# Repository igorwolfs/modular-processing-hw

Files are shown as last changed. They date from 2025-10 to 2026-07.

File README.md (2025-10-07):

# MCU-BOARD

## Acoustic-carrier Project
The goal is to design a small CPU board, with some RAM and connectors, that can
- Drive the piezo-driver / inverter board
- Save about 1 second of data from 2 30 MHz ADC's
	- Reflection at origin-piezo
	- Transmission from origin to second-piezo
- Processing of the data on the MCU in the next few seconds
- Storage of the processed data on an SD-CARD
- Transmission of the processed data over Hi-Speed USB / Ethernet to a computer

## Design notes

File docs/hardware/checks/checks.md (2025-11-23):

# MCU
## STM32
- LPN: ok
- MPN: ok

### Schematic
- Pins OK -> Compared with output on footprint vs STM32 output
- Make still check BS0/BS1 for wrong outputs

### Footprint
- Check footprint dimensions
	- Looks good

## Resonator
- LPN: ok
- MPN: ok

### Schematic
- pin2, 4 -> GND
- pin 1, 3: connected to res
	- 4.7 pF capacitors

### Footprint
- Looks good

## Button
- LPN: ok
### Footprint
- ok

# SDRAM
## BA / BS
and bank address (BA), also
known as bank select (BS).

## Schematic
- Connections look ok

## Footprint
- Check pin number vs Symbol number
- Footprint: 
	- Package_SO:TSOP-II-54_22.2x10.16mm_P0.8mm
- SDRAM looks ok

# USB
## USB Receptacle
- USB_C_Receptacle_HRO_TYPE-C-31-M-12
- Looks good (footprints + pinout)

## USB ESD protection

- Package_TO_SOT_SMD:SOT-23-6

## Resistive pull-up
- Resistor_SMD:R_Array_Convex_4x0603
- Footprint: ok

## SDMMC
### Schematic
- pins vs footprint:

### Footprint

### Layout
TODO:
- Keep skew below 10 mm
- Add pull-up on cmd line?
	- CMD line must have pull-up as well
	- https://community.st.com/t5/stm32-mcus-products/using-sdmmc-sdio-and-fatfs-for-reading-sd-card-for-stm32l471vgt6/td-p/689667

DONE

## Connectors
- Plug_Hirose_DF40_2x40_DF40C-80DP-0.4V (DF40C-80DP-0.4V(51))
- Footprint: iw-connector:HRS_DF40C-80DP-0.4V(51)

### Footprint
- Looks correct -> number of pins is also correct
- Pin indicators (uneven / even), instead of counting as in jlc -> but ok

# ADC Frontend
- Reference buffering: checked, should work
## THS4521
- Looks ok
- Pins: ok
### Footprint: ok

## Everything else: looks ok

# Power
- AMS1117-3.3: looks ok

## Footprint package: looks OK

## SDRAM length matching

### First connection
- CLK: 38.7 mm
- A0..A12
	- A0: 46
	- A1: 46
	- A2: 47
	- A3: 47.9
	- A4: 40.3
	- A5: 36 mm
	- A6: 40.9 
	- A7: 39
	- A8: 35
	- A9: 34
	- A10: 44
	- A11: 34
	- A12: 35
- BS0..1: 
	- BS1: 34
	- BS0: 33
-> ALL OK
- D0..16
	- D0: 38.7
	- D1: 32
	- D2: 41
	- D3: 42
	- D4: 36.3
	- D5: 35
	- D6: 37
	- D7: 36.3
	- D8: 31
	- D9: 30
	- D10: 30
	- D11: 30.5
	- D12: 30.5
	- D13: 34
	- D14: 31.6
	- D15: 32.8
- Other
	- nRAS: 48
	- nCAS: 44
	- nWE: 47
	- LDQM: 47.5
	- UDQM: 37.2
	- nCKE0: 49

### Second connection
- CLK: 68 mm
- A0..A12
	- A0: 71.8
	- A1: 72
	- A2: 72
	- A3: 73
	- A4: 64
	- A5: 66
	- A6: 63
	- A7: 63
	- A8: 60
	- A9: 66
	- A10: 68
	- A11: 62
	- A12: 65
- BS0..1: 
	- BS1: 69
	- BS0: 66
- D0..16
	- D0: 64
	- D1: 62
	- D2: 69
	- D3: 66
	- D4: 62
	- D5: 61
	- D6: 61
	- D7: 60.3
	- D8: 60
	- D9: 60
	- D10: 62
	- D11: 65
	- D12: 63
	- D13: 66
	- D14: 61.3
	- D15: 61
- Other
	- nRAS: 74
	- nCAS: 68
	- nWE: 73
	- LDQM: 73
	- UDQM: 65
	- nCKE1: 65

## PSSI length matching
- PDCK: 34 mm
- D8: 56.3 mm
- D12: 54 mm
- D13: 51 mm
- D6, D7: 17 mm

Increase PDCK to 45 mmm
- Match everything to +-15 mm

## SDMMC length
- D0..D3
	- D0: 76
	- D1: 81
	- D2: 83
	- D3: 85
- CD: 88
- CMD: 81

# Differential Impedances
- ADC: OK
- USB: OK

# PSSI impedance

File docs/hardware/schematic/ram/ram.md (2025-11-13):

# CPU Memory Controller
## NOR Flash / PSRAM controller
- Asynchronous SRAM and ROM
- PSRAM (cellurar RAM)
- NOR Flash memory

## Clock speed
- Programmable continuous clock (FMC_CLK) output
	- Can be used as MCO for synchronous access (Read / Write)
- Maximum FMC clock is 150 MHz

# Types of RAM
## PSRAM
- Pseudo-static random access memory
	- Acts as DRAM, looks like SRAM
	- It has internal circuitry for memory refreshing

##  SRAM
Static random access memory. 
- Static: data retainment without refreshing

## DRAM
Dynamic random access memory
- Dynamic: needs refreshing
- Slower than SRAM

# Options

## PSRAM

It seems like PSRAM is a good option, apart from the fact that the biggest size in which I can find it is 64 MBit.

### IS66WVE4M16EBLL-70BLI
64 MBit PSRAM (8 MBytes)
- BGA package (TFBGA-48)
- 4.33 dollars

## SRAM
- Only one availabla seems one with QSPI, and SSOP package
- Seems like I can only find them in small sizes (at most 144 MBit), and at high sizes they are crazy expensive.

### VTI7064MSME
- Too slow (probably QSPI only)
- Good package
- Cheap
- 64 MBit (not enough)

### CY7C2665KV18
- 30 dollars
- 550 MHz clock support

### S27KL0642DPBHI020
- Self refreshing DRAM (PSRAM)
- BGA24
- Hyperbus
- 5.49 dollars

## SDRAM
- They seem to all be in TSOP package, none of them in BGA

### Winbond: W9825G6KH-6
Speed: up to 200 MBit/second

- TSOP-54-10.2mm (non BGA!!!)
- 166 MHz
- 256 Mbit (32 MByte)
- 1.38 dollars

#### Question 1
How can we access 256 MBit of data if there are only 13 address bits
- 2**13 = 8192 words.

### Micron: MT48LC16M16A2P-6A
- 4 Meg x 16 x 4: 256 MBit (32 MByte)
- 166 MHz
- 5.22 dollars
- TSSOP

### Micron MT48H16M32LFB-6
- MT48H16M32LFB5-6 IT:C TR
- 512 Mbit
- 4.95 dollars
- BGA package 
- Mobile LPSDR RAM

# Winbond: W9825G6KH-6
## Power
- Power supply: 3V3

## Symbol + footprint check
- PINS OK
- FOOTPRINT OK

# Examples
## Soldering Inkplate
Path: Soldered-Inkplate-MOTION-STM-board-hardware-design/CAD
### Decoupling Capacitance
- 2 x 1 uF
- 2 x 7 x 100 nF
- 2 x 10 nF
- 3 x 1 nF

### Ferrites
- None
- Vdd, vddq connected
## Icepi Zero

### Decoupling
- 7 x 22 nF
- 1 x 10 uF

### Ferrites
- None
- Vdd, vddq connected

# Implementation
## Trace lengths:
### Clock: 40 mm
### Address bus
- A0: 45 mm
- A1: 46.5 mm
- A2: 47 mm
- A3: 48 mm
- A4: 38 mm
- A5: 37 mm
- A6: 40 mm
- A7: 39 mm
- A8: 35 mm
- A9: 34 mm
- A10: 44 mm
- A11: 33.55 mm
- A12: 34.165 mm

### Data bus
- D0: 38.5 mm
- D1: 31.3 mm
- D2: 40 mm
- D3: 41 mm
- D4: 36.3 mm
- D5: 35.7 mm
- D6: 36.68 mm
- D7: 37.3 mm
- D8: 31 mm
- D9: 30 mm
- D10: 30 mm
- D11: 31 mm
- D12: 30 mm
- D13: 30 mm
- D14: 31.645 mm
- D15: 35 mm

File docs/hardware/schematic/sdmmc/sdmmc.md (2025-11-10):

# SDMMC

## Hardware design
### Pull-ups / downs
- CMD + DATA[0..3] lines must be pulled up by 10 kOhm resistors
	- https://docs.espressif.com/projects/esp-idf/en/stable/esp32/api-reference/peripherals/sd_pullup_requirements.html
	
## Pins

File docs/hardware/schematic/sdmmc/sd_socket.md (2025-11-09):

# The SD Socket
The SD card socket has 4 pads on the metal shielding and 11 pinouts (also pads, at the back). An online search reveals that the pinouts of these components are fairly standard. That’s understandable given the fungible / standardized nature of the cards themselves.

Many of the pins simply connect directly through to the pads of the SD card itself. So let’s consider those:

- DAT3 / CS
- CMD / DI
- VSS1
- VCC
- CLK / SCLK
- VSS2
- DAT0 / DO
- DAT1
- DAT2

The very small microSD cards have only 8 pins. On those there is only one VSS pin.

To these, the SD card slot adds three pins:

- Card Detect (CD)
- Common Switch
- Write Protect (WP)

Note: only eight of the pins are used in this project.

## Power Pins
Pins VSS1, VSS2 and VCC relate to power supply.

### Vss
VSS stands for voltage source and is where ground should be connected. On other schematics it may be labelled as GND.

### Vdd
VDD stands for voltage drain and is where positive power should be connected. On other schematics it may be labelled as VCC, which stands for voltage collector.

## Data Pins

SD cards can be operated in SPI (serial peripheral interface) mode or native operating mode. Because the SD card can be attached to most microcontrollers via a generic SPI interface or some GPIO ports it is a suitable for many projects. Therefore we will discuss pins as they are used in this mode.

### SPI 
The SPI protocol defines a host and slave relationship, described at http://elm-chan.org/docs/spi_e.html 105. This is important to remember in the reading of the pins below. Also, throughout these notes I use the terms host and microcontroller interchangeably.

### DAT3 / CS

This is the Data 3 pin in native mode and Chip Select pin in SPI mode. It is used by the SPI host (in our case, the microcontroller) to indicate that it’s communicating with the slave. It can also be used by the slave to indicate to the host it is ready to communicate.

This functionality means the data out and data in pins can be part of a shared data bus (with other SPI slave devices on it).

### CMD / DI
This is the Command pin in native mode and Data In pin in SPI mode. It is used by the SPI host to send serial data (bit by bit) to the SD card (the slave) and is sometimes referred to as Master-Out Slave-In (MOSI).

### DAT0 / DO
This is the Data 0 pin in native mode and Data Out pin in SPI mode. It is used by the SPI slave to send serial data (bit by bit) to its host (the microcontroller) and is sometimes referred to as Master-In Slave-Out (MISO).

### CLK / SCLK
This is the Clock pin in both modes. It is used by the SPI host to provide a clock pulse for the purposes of sending and receiving data on the DI and DO pins.

## Card Slot Pins
### Card Detect (CD)

This pin is used to detect whether a card has been inserted in the slot. The mechanism by which this is done seems common across slot models (based on a random sampling of datasheets available online): the pin is connected to a mechanical switch which closes when the card is inserted and connects to ground on the other side. On the one we are using, the switch mechanism is exposed and clearly visible on the top of the slot (in the cut-away section of the shielding). Insert a card and you will see how the bent piece of metal (part of the shielding) touches another piece of metal. You can use a multimeter to test that the second piece of metal is connected to the CD pin and the bent piece (and indeed the entire shielding) is connected to ground.

To use the card detect functionality you would connect the CD pin to a positive power rail via a pull-up resistor so that you get a high signal when the slot is empty and a low signal when a card is inserted. This functionality is not used in this project.

This pin is also connected to the Common pin when a card is inserted and disconnected from the Common pin when there is no card inserted. This is an alternative way of using the pin.

### Write Protect (WP)
This pin is used to detect whether an inserted card has got Write Protect enabled. As with the CD pin, this is connected to ground when a card is inserted Write Protect on and you would need to have it pulled-up in order to use it.

As with the CD pin, this pin is connected to the Common pin when Write Protect is inserted and otherwise disconnected from the Common pin.

### Common Switch
Both the CD and WP pins above are connected to this pin, in addition to ground, when they are activated, providing another way for us to implement that functionality.

# Source:
- https://community.circuitmess.com/t/understanding-the-sd-card-slot/2801

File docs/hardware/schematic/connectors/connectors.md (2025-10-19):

# Connectors

We have 2 options
- Using high-speed edge connectors
- Using high-speed vertical connectors
- Using high-speed 90-degree angle connectors

## 90 degree vertical connectors
The main issue with those kind-of connectors is the pricepoint. Mechanical connectors with the ability to hold other PCB's at a 90 degree up-right are pretty expensive.

## vertical connectors
They are cheaper, however in order to use those we need
- OR mechanically small components in the space between the 2 boards (otherwise they mide impede the connection between the 2 boards)
- OR double-sided component assembly

Given the lower price-point we're aiming for, we'd want to do single-sided assembly only. Connectors put on top won't make the board connect unless we put the larger components on one side and only connect on the edge of the board.

The advanced ones of this version also only work for standard assembly, not for economic assembly.

### HC-PBB40C-100DS-0.4V-4.0-02
- VERY EXPENSIVE: 1.5 euros a pop
- Economic assembly

###  HRS Hirose
- Price is OK (0.69 + 0.94) for 90 connections
- DF40C-90DS-0.4V(51)
- DF40C-90DP-0.4V(51)
- Enough in stock
- Economic assembly

- There's a 100 or even a 120 pin variant of it as well: might be a better option, in this case we need only a single one
	- 120 is the biggest one -> But not that many available. 
	- Take either the 100 or the 90 pin variant.
	- 90 pins -> max 45 connections (if no power)
	- 100 pins -> max 50 connections (if no power)

BIG PRO:
- It seems like the height of these connectors can be higher than other components
- So we might get away with putting it centrally on the boards with other components around it instead of banning it to the edge because it would otherwise interfere with other IC's mechanically

## Edge-board connectors
Edge-board connectors are a good alternative, since they need to only be placed "on the edge".
They are however pretty expensive and there's not that many of them available with good pin amounts.

### DF36-15S-0.4V(51)
- 0.446 euros per piece
- Economic assembly

# Choice
- DF40C-80DP-0.4V(51)

Stacking height: 1.5 mm

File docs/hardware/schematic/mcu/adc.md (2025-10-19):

# ADC (STM32H723ZGTx)
3 ADC's:
- 2 16 bits ADC's
	- ADC1, ADC2
	- Interleaved mode
	- Can work at 7.2 MHz
	- 16-bit ADC1 and ADC2 in double-interleaved mode at 7.2 MHz
	- 3/4 fast channels (PA6, PB1, PC4, PF11, PF13)
	- 11/12 slow channels
- ADC3 at 7.1 - 8.3 MSPS (12 bits)
	- 2 direct channels (PA0_C, PA1_C, PC2_C and PC3_C)
	- 6 fast channels

## Channel choice

3. Direct channels are connected to analog I/Os (PA0_C, PA1_C, PC2_C and PC3_C) to optimize ADC performance.
4. Fast channels correspond to PA6, PB1, PC4, PF11, PF13 for ADCx_INPx, and to PA7, PB0, PC5, PF12, PF14 for
ADCx_INNx.

Direct channels: connected to analog I/Os 
- PA0_C, PA1_C, PC2_C and PC3_C
	- So connect the 2 ADC's to one of these pins in interleaved mode
	- Choose PA0_C/PA1_C -> fast channel

Fast channels:
- PA6, PB1, PC4, PF11, PF13 for ADCx_INPx
- PA7, PB0, PC5, PF12, PF14 for ADCx_INNx
	- Connect the 3rd channel to one of the INPx pins
	- Choose PB0/1 -> fast channel

## Min / Max values

## Modelling
- Sample-and-hold capacitor: 4 pF
- Sampling time: 1.5-810.5 	times  1/f_adc
- Equivalent static impedance
	- Varies between 170 ohms and 26.5 kOhm
	- Table 78. Minimum sampling time vs RAIN (16-bit ADC)(1)(2) gives a more detailed image of the ADC input impedance

### Internal buffering
- The ADC requires an external on-chip buffer?
	- It does, the impedance of the signal will likely be too high, even coming from a buffering board.
	- So we'll go for an on-CPU differential-input ADC sampling

# ADC Model
## Connection diagram (Figure 38)
- $R_{ADC}$
- $C_{ADC}$
- $C_{parasitic}$: PCB capacitance + pad capacitance (4 pF)
- $R_{source}$

## Parasitics
### 12-bit ADC
-

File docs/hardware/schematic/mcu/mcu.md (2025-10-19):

# Possible Choices

## STM32H72

- PRO: 
	- better ecosystem
	- Non-BGA
	- Easier development
	- DSP capabiltiy
	- SRAM/SDRAM/PSRAM (max frequency: 150 MHz)
- CON: 
	- more expensive
	- No RGMII
	- External RAM required

## Allwinner

- PRO:
	- Non-BGA
	- Cheaper
	- RGMII
- CON:
	- parallel inputs channel?
	- Support?

It seems in general that Allwinner is not used that often in devices.

# CPU requirements
The most important requirements for the CPU are
- There must be an ethernet interface (preferably RGMII, RMII also allowed)
- There must be a ULPI interface for HI-SPEED USB2.0
- There must be an SDRAM / SRAM / PSRAM  controller
- The clock speed must be above 200 MHz, the data to be read from the ADC (MS)
	- This one has a 10-bit pin interface.
- The package MUST NOT be a BGA, these are way too hard to debug.
- 1 MCO output to drive the ADC

## ADC
### Internal ADC
- Single / dual channel ADC
- 

### Alternative
- Downsampling / decimation of ADC data before in small DSP CPU

## USB
- ULPI interface

## SDRAM
### Data transfer requirements
- Data transfer:
	- 30 MHz x 2 bytes -> 57.3 Mbytes / second
	- Should be able to save at least a second of data

### Peripheral (stm32h72)
FMC (Flexible memory controller), can handle
- SRAM
- NOR flash / OneNAND flash
- PSRAM
- NAND
- DRAM (SDRAM Mobile LPSDR SDRAM)

#### Busses
- Address bus
	- Single address bus for all peripherals
- Different chip select for all peripherals
- Data bus
	- 8, 16 or 32-bits wide

#### Specs (SDRAM)
- SDRAM: Maximum speed for synchronous access is:
	- The FMC_CLK / FMC_SDCLK frequency divided by 2
- Address bit 13 max
- 2 NSS bits
- Write / Read fifos (16x32 bits)

Check the devboard for comparison
- SDRAM conflicts with

#### Banks
Bank 1 (NOR / PSRAM)
- Chip Selects: can handle 4x64 MB = 256 MB

Bank 2, 4
- Not used

Bank 3:
- Addressing NAND flash memory devices

Bank 5, 6:
- SDRAM devices: each bank here can handle 4 x 64 = 256 MB -> 512 MB togethery
- NOTE: SDRAM and ULPI interface are mutually exclusive!

## Ethernet
- RGMII interface

## DSP
- Full DSP instruction set

### FMAC
- Fixed point multiplier and accumulator
	- 16x16 bit multiplication
	- Can realize FIR and IIR filters

## SPI
### Specs
- SPI, QSPI, OCTSPI all possible 
	- OCTSPI mostly used for hyperbus (memory)
- Max SPI speed

## Clock output
- 2 x MCO output

Note: Input clock for MS9280 is +5 / +3V3 CMOS

## Parallel interfaces
Note: 
- The input data comes from the MS9280 A/D converter at 35 MHz. CMOS 3V3 or CMOS 5V (depending on input voltage)
	- LOW: 0.4 V
	- High: 2.8 V

### Camera interface
- 8-14 bit camera interface
- DCMII: CMOS 8-14 bit parallel interface, with data-rates up to 140 Mbyte/s at a 80 MHz clock

### 16-bit parallel slave synchronous interface
- CMOS / Parallel LVDS style serializer
	- PSSI: synchronou 8/16-bit data in/out slave
		- contains 8-word fifo
		- Can reach up to 140 MByte/s, 80 MHz pixel clock
		- So time multiplexing is A POSSIBILITY!
Choose this one.

### GPIO sampling + DMA
- timer with automatic input sampling and passing on to DMA

## DMA
### DMA2D
- 

# CPU Peripheral Selection
## FMC
FMC 2xSDRAM bus since SDRAM is faster and cheaper. It's the only one providing adequate speed.

### Signals
- Address bus (13 bits): A0..A12
- SDNWE (WE)
- CKE1, CKE2: 2 separate clock enable signals, one for each SDRAM
- NE1, NE2: (NOT) chip enable, one for each SDRAM
- BL0, BL1: Upper and lower byte enable for IC.
- NCAS: CAS# (column select for address)
- NRAS: RAS# (row select for address)

## Parallel Bus
### PSSI 
WARNING: mutually exclusive with the DCMI.

Parallel synchronous slave
- 8 / 16-bit communication between MCU's / MCU and FPGA.
	- Choose 16-bit communication

- Has DMA with 8-word FIFO.
- Data transfer polarity
	- CKPOL = 0:
		- Input sampled on CLOCK FALLING EDGE
		- Output driven on CLOCK RISING EDGE
	- CKPOL = 1:
		- Input sampled on CLOCK RISING EDGE
		- Output driven on CLOCK FALLING EDGE
	- Note: Setting PSSI into sending OR receiving mode can only be done when peripheral is deactivated

### Interrupt
- PSSI_OVR

### Speed
- AHB clock must be >=  2.5 times the frequency
- CLK MAX: 550 MHz
	- 550 / 2.5 = 220 MHz is the absolute maximum

### Pinout
- PSSI_RDY: (output) signal coming from the CPU itself indicating cpu readiness to sample data
- PSSI_VALID: (input) signal coming from another CPU / FPGA indicating data is valid
- PSSI_CLOCK:
	- Clock polarity (data can be captured / transmitted on EITHER rising OR falling edge)
- PSSI_DE: indicates data in the next cycle will be valid and will thus need to be sampled.

## USB
- Battery charger detection
- 12 Mbi/s (full-speed USB)

### Pinout
- USB_OTG_HS_DP
	- Internal 1k5 ohm on D+ line
- USB_OTG_HS_DM
- (USB_OTG_HS_ID) - UNNECESSARY, ONLY FOR USB micro A/B OTG
	- Determines whether device acts as host or peripheral
	- Only possible with USB micro A, micro B
- USB_OTG_HS_VBUS
	- VBUS (5 V) can be connected here
	- CPU has internal regulator capable of regulating its own 3v3 supply
	- Should be connected with a resistive divider of 5_INPUT - 4.7k - VBUS - 10k - GND
- (USB_OTG_HS_SOF) - UNNECESSARY, MOSTLY FOR AUDIO APPLICATIONS

### Question: Does the USB_OTG_HS_VBUS have any use as a Vsense pin when power is supplied externally?
- 

## SPI / SD-CARD
- Add an SPI peripiheral so I can read / write from an sd-card.
	- Might come in handy when saving large amounts of data is necessary (e.g.: when doing testing)

### Pinout
- SDMMC2_D0, SDMMC2_D1, SDMMC2_D2, SDMMC2_D3 (Data lines)
- SDMMC_CKN
- SDMMC2_CMD
- SDMMC2_CK

# Power Pin routing / Decoupling
- Check Table 2 in AN5419

## VDD
- 100 nF for each VDD
- 4.7 uF connected to one VDD

## VDDA
- 1 uF ceramic
- 100 nF close to the pin

## VBAT
- Connect to VDD
- 1 uF ceramic
- 100 nF close

## VCAP
- 100 nF close to each VCAP pin
- VCAP pins connected together

## VDD33USB
- 1 uF ceramic
- 100 nF ceramic (if USB reg not used)
- Internally tied to VDD

## VREF+
- 1 uF ceramic
- 100 nF ceramic
- Should be tied to the external reference voltage used for ADC
	- Check voltage used in ADC-board, perhaps provide this voltage to VREF if needed

## PDR_ON
- if HIGH: POR and PDR circuitry is ON
- if LOW: POR and PDR circuitry is OFF
	- So tigh high with 0 ohm resistor

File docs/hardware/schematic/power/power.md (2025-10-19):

# Power
We need a way to select one of 3 power input source
- 3V3 through connector
- 5 V through USB VBUS
- 5 V through pins

## Power consumption
- MCU: < 200 mA
- SDRAM: 60 mA x 2 = 120 mA
- ADC frontend: 5 mA

So: 330 mA * 1.3 V = 430 mWatt max dissipation.

Use the AMS1117-3.3

## Solution
- Buck converter
- LDO
	- The power required here is not that high. 
	- An LDO should do the job if isolated enough.
	- Warning: 
		- The dropout voltage might be too high. So you must make sure that you have an ideal diode in parallel driving the load in case the input voltage is 3V3
			- Or maybe foresee 2 pins here

So TODO:
- 1 connection from vbus to LDO
- 1 connection from piezodriver-vin-connector to LDO (in case supply 5 V)

So 2x2 connector here:

- 1 connection from LDO to 3V3
- 1 connection from large vin-connector to 3V3 (in case)
- 1 connection from piezodriver-vin-connector to 3V3

So 3x2 connector here:

## Overvoltage protection
- Add a resettable overcurrent fuse
- Add reverse voltage breakdown protection
	- Choose SMF3.3CA for the input at 3V3
	- Choose SMF7.0CA for the input at 5V-6V

Diode package: SOD-123FL

### Package check
- Dimensions look good

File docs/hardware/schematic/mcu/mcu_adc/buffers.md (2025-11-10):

# Buffer requirements
- GBW of at least 10 MHz

# Buffer examples
## INA333 (instrumentatino)
- BW: 150 kHz
- SR: 0.16 V/us
- Noise
	- @1kHz: 50 nV/sqrt(Hz)
- https://www.ti.com/lit/ds/symlink/ina333.pdf?ts=1760662953933

## OPA695 (precision)
- Good bandwidth
- More expensive

## AD8031
- GBW: 80 MHz
- SR: 30 V/us
- Price: 2+ euros
- Noise
	- @1kHz: 15 nV/sqrt(Hz)
- https://jlcpcb.com/api/file/downloadByFileSystemAccessId/8588901762816622592

## LTC6268
- Good bandwidth (500 MHz)
- Very low input impedance ()
- WAAAYY too expensive

## THS4521
- price: 0.8 $
- GBW: 145 MHz
- SR: 490 V/us
- Input voltage noise
	- > @10kHz
		- 4.6 nV/sqrt(Hz)
- Noise
	- @100 kHz: 
- Good option, bandwidth 40.7 MHz
- Maybe even a bit too much for our application

Seems like the best option
- The only thing that is quite shitty is the DC-offset for this one.

# THS4521
Images adc12, and adc3 were the resulting choices, some simulations can be found in the simulations/tina_ti folder that show the transfer function of these buffers with a dynamic load modelled after the stm32 parameters found in the datasheet.

# Vref requirement
- What should the vref be?
	- buffered vdda/2?
	- vdda?

## Measurement range for the dfferential ADC
### Table 184. ADC characteristics(1)(2) (continued)
- Conversion voltage range: 
	- 0..VREF+
- Common mode input voltage:
	- -Vref/2-10% .. Vref/2+10%

### What is the point of vref+?

It can be
####  Internal
#### External
- Then it should be supplied

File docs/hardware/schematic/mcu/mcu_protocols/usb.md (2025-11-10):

# USB
- a USB-pull-up resistor should be internal
	- Check reference schematic for nucleo
	- Check application ntoe

# SWD
- SWD-bus has no pull-ups present on the nucleo board.
- SWD-bus has both pull-ups and pull-downs present.
	- NJTRST: internal PU
	- SWDIO: pu
	- SWCLK: pd

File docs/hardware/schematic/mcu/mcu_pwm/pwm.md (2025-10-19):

# MCU PWM
- Advanced control timers: TIM1, TIM8
- We must generate 4 complementary signals at frequencies up to 10 MHz.

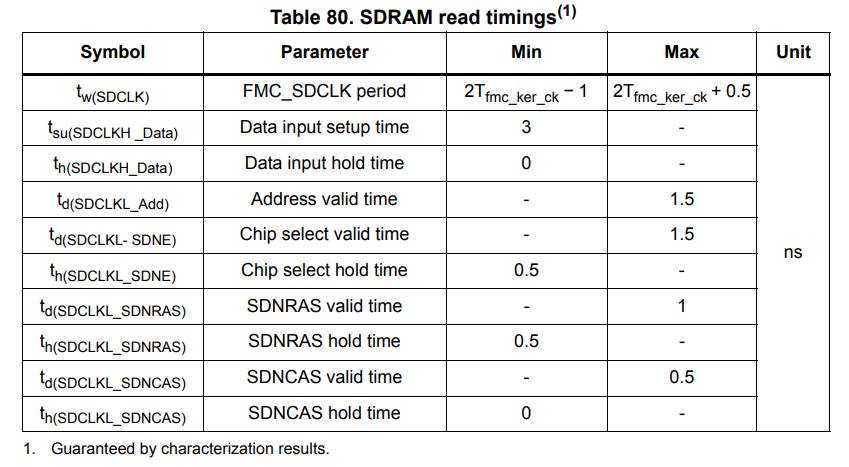
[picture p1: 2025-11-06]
docs/hardware/layout/FMC/rtime_st.png

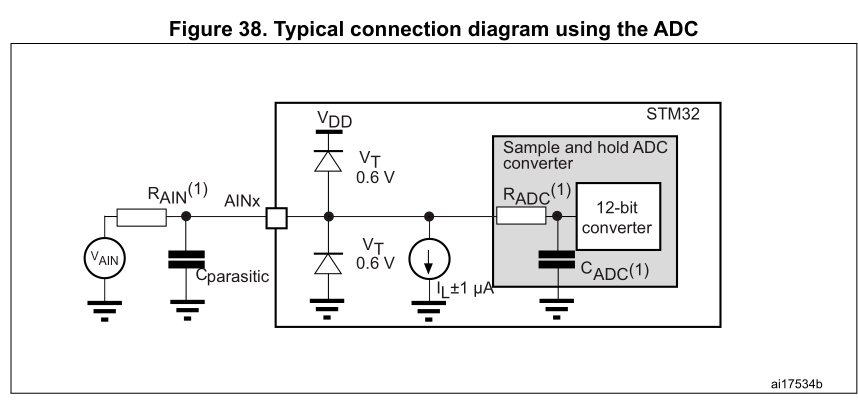
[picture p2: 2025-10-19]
docs/hardware/schematic/mcu/images/adc_connection_diagram.png

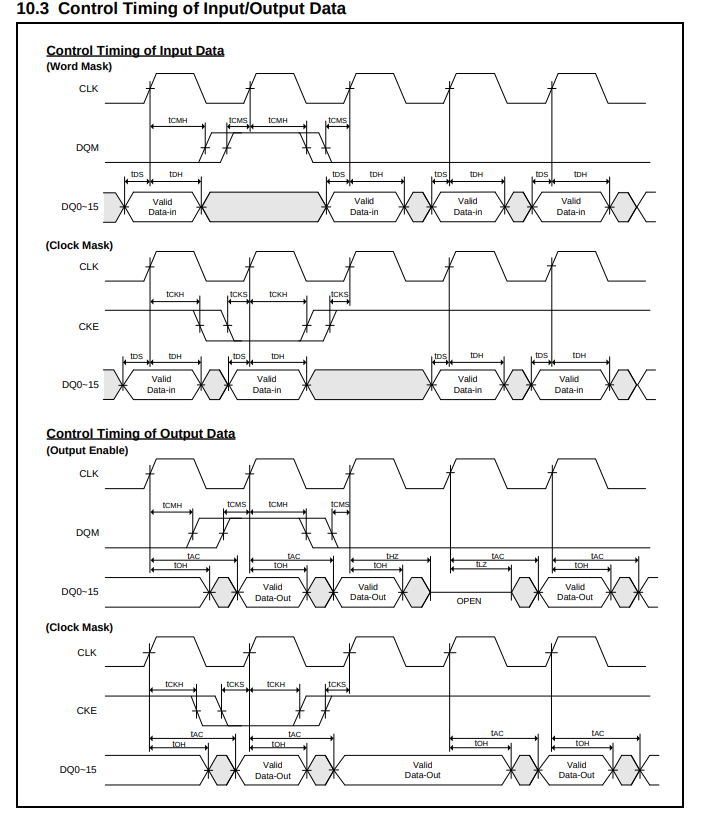
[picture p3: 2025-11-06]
docs/hardware/layout/FMC/rwwave_wb.png

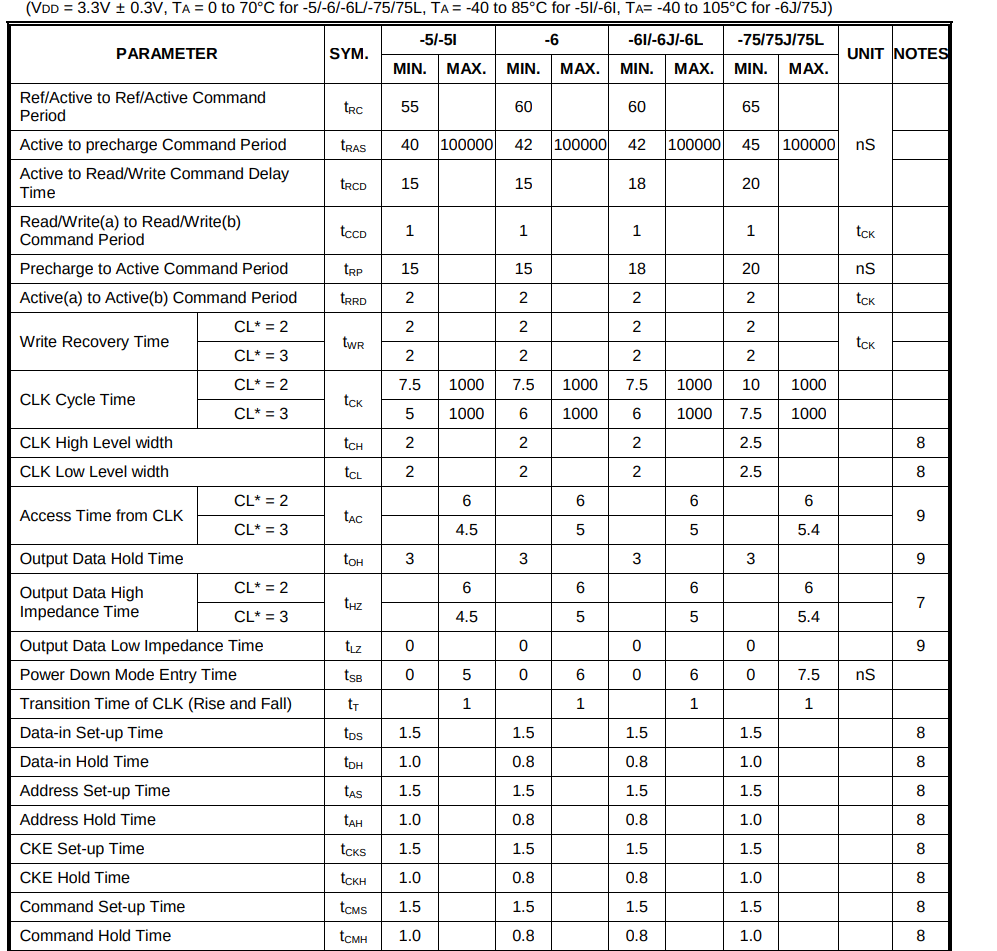
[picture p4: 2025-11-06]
docs/hardware/layout/FMC/rwtime_wb.png

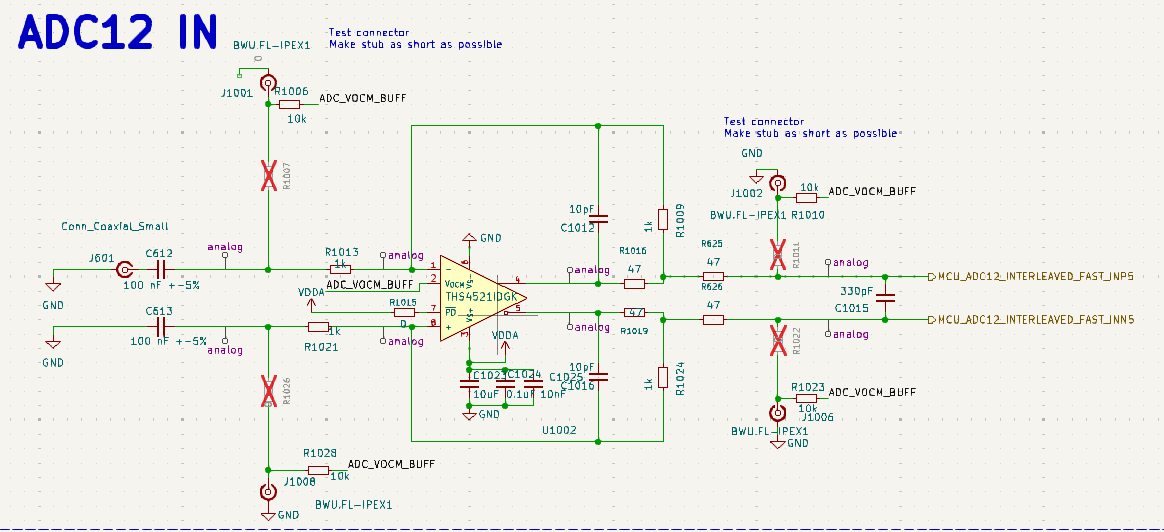
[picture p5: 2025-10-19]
docs/hardware/schematic/mcu/mcu_adc/images/adc12.png

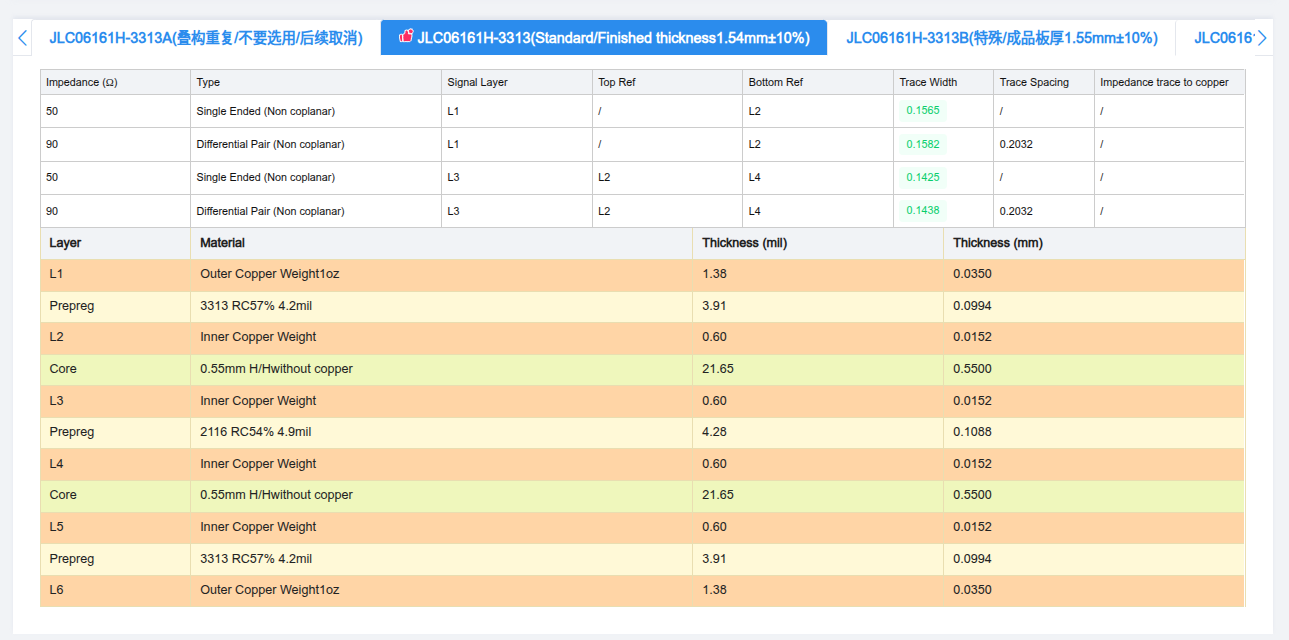
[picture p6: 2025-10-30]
docs/hardware/layout/impedance/jlc06161h-3313.png

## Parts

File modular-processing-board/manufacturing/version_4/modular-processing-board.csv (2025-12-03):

Reference | Qty | Value | Footprint | LPN | MPN
C201,C1227 | 2 | 20pF | Capacitor_SMD:C_0402_1005Metric | C1554 | 0402CG200J500NT
C202,C203,C204,C205,C206,C207,C208,C209,C210,C211,C212,C213,C214,C216,C217,C218,C220,C222,C224,C301,C302,C303,C304,C305,C306,C307,C308,C309,C310,C311,C313,C401,C601,C604,C605,C606,C607,C608,C617,C807,C1024,C1101,C1103 | 43 | 0.1uF | Capacitor_SMD:C_0402_1005Metric | C307331 | CL05B104KB54PNC
C215,C219,C221,C223 | 4 | 1uF | Capacitor_SMD:C_0805_2012Metric | C28323 | CL21B105KBFNNNE
C312,C701,C702,C703,C1107 | 5 | 22uF | Capacitor_SMD:C_0603_1608Metric | C59461 | CL10A226MQ8NRNC
C602,C618,C1025 | 3 | 10nF | Capacitor_SMD:C_0402_1005Metric | C15195 | CL05B103KB5NNNC
C603 | 1 | 220nF | Capacitor_SMD:C_0402_1005Metric | C16772 | CL05B224KO5NNNC
C609,C615,C1012,C1016 | 4 | 10pF | Capacitor_SMD:C_0603_1608Metric_Pad1.08x0.95mm_HandSolder | C1634 | CL10C100JB8NNNC
C610,C612,C613,C614 | 4 | 100nF | Capacitor_SMD:C_0603_1608Metric | C14663 | CC0603KRX7R9BB104
C611,C1015 | 2 | 330pF | Capacitor_SMD:C_0603_1608Metric_Pad1.08x0.95mm_HandSolder | C1664 | CL10C331JB8NNNC
C616,C619,C813 | 3 | 4.7uF | Capacitor_SMD:C_0402_1005Metric | C23733 | CL05A475MP5NRNC
C804,C805 | 2 | 220pF | Capacitor_SMD:C_0402_1005Metric | C1530 | 0402B221K500NT
D201,D401,D602 | 3 | RED | LED_SMD:LED_0603_1608Metric | C2286 | KT-0603R
D703 | 1 | SMF3.3CA | Diode_SMD:D_SOD-123F | C19077496 | SMF3.3CA
F2 | 1 | BSMD1812-050-15V | Fuse:Fuse_1812_4532Metric | C883139 | BSMD1812-050-15V
FID101,FID102,FID103,FID104 | 4 | Fiducial | Fiducial:Fiducial_1mm_Mask2mm
H101,H102,H103 | 3 | MountingHole | MountingHole:ToolingHole_1.152mm
J201 | 1 | Conn_ARM_SWD_TagConnect_TC2030 | Connector:Tag-Connect_TC2030-IDC-FP_2x03_P1.27mm_Vertical
J202 | 1 | Conn_02x06_Odd_Even | Connector_PinHeader_2.54mm:PinHeader_2x06_P2.54mm_Vertical
J401 | 1 | TF01A | iw-memory:TF01A | C2889258 | TF-01A
J501 | 1 | Plug_Hirose_DF40_2x40_DF40C-80DP-0.4V | iw-connector:HRS_DF40C-80DP-0.4V(51) | C294544 | DF40C-80DP-0.4V(51)
J502 | 1 | Conn_02x06_Odd_Even | Connector_PinSocket_2.54mm:PinSocket_2x06_P2.54mm_Vertical
J601,J604 | 2 | Conn_Coaxial_Small | Connector_Coaxial:SMA_Amphenol_901-144_Vertical | C496549 | BWSMA-KE-Z001
J602,J1001 | 2 | BWU.FL-IPEX1 | iw-connector:BWU.FL-IPEX1 | C5137195 | BWU.FL-IPEX1
J701 | 1 | Conn_02x02_Odd_Even | Connector_PinHeader_2.54mm:PinHeader_2x02_P2.54mm_Vertical
J801 | 1 | TYPE-C-31-M-12 | Connector_USB:USB_C_Receptacle_HRO_TYPE-C-31-M-12 | C165948 | TYPE-C-31-M-12
JP202 | 1 | SolderJumper_2_Bridged | Jumper:SolderJumper-2_P1.3mm_Bridged2Bar_Pad1.0x1.5mm
JP602 | 1 | SolderJumper_2_Open | Jumper:SolderJumper-2_P1.3mm_Open_Pad1.0x1.5mm
L701 | 1 | GZ2012D101TF | Inductor_SMD:L_0805_2012Metric | C1015 | GZ2012D101TF
R201 | 1 | 4.7k | Resistor_SMD:R_0402_1005Metric | C25900 | 0402WGF4701TCE
R203,R207,R217,R218,R616,R620,R1001,R1015,R1201 | 9 | 0 | Resistor_SMD:R_0603_1608Metric | C21189 | 0603WAF0000T5E
R206,R209 | 2 | 1k | Resistor_SMD:R_0402_1005Metric | C11702 | 0402WGF1001TCE
R208,R401,R402,R608,R609,R610,R612,R627,R628,R629,R1006 | 11 | 10k | Resistor_SMD:R_0603_1608Metric | C25804 | 0603WAF1002T5E
R210,R216 | 2 | 470 | Resistor_SMD:R_0402_1005Metric | C25117 | 0402WGF4700TCE
R214,R215,R614,R615,R617,R618,R625,R626,R1016,R1019 | 10 | 47 | Resistor_SMD:R_0603_1608Metric | C23182 | 0603WAF470JT5E
R601,R603,R605,R606,R611,R613,R619,R621,R1009,R1013,R1021,R1024 | 12 | 1k | Resistor_SMD:R_0603_1608Metric | C21190 | 0603WAF1001T5E,0603WAF1001T5E
R602 | 1 | 75 | Resistor_SMD:R_0603_1608Metric | C4275 | 0603WAF750JT5E
R604 | 1 | 1k5 | Resistor_SMD:R_0603_1608Metric | C22843 | 0603WAF1501T5E
R607 | 1 | 4.7k | Resistor_SMD:R_0603_1608Metric | C23162 | 0603WAF4701T5E
R703 | 1 | 1k5 | Resistor_SMD:R_0402_1005Metric | C25867 | 0402WGF1501TCE
R804,R805 | 2 | 5.1k | Resistor_SMD:R_0603_1608Metric | C23186 | 0603WAF5101T5E
R809,R810 | 2 | 33k | Resistor_SMD:R_0603_1608Metric | C4216 | 0603WAF3302T5E
RN707 | 1 | 4x10k | Resistor_SMD:R_Array_Convex_4x0603 | C29718 | 4D03WGJ0103T5E
SW201,SW602 | 2 | SW_Push | iw-misc:SW_TS-1088-AR02016 | C720477 | TS-1088-AR02016
TP201,TP202,TP401,TP402,TP403,TP404,TP601,TP602,TP701 | 9 | TestPoint | Connector_PinSocket_1.27mm:PinSocket_1x01_P1.27mm_Vertical
U201 | 1 | STM32H723ZGTx | Package_QFP:LQFP-144_20x20mm_P0.5mm | C730146 | STM32H723ZGT6
U202,U401 | 2 | SRV05-4 | Package_TO_SOT_SMD:SOT-23-6 | C20615829 | SRV05-4A
U301,U302 | 2 | W9825G6KH-6 | Package_SO:TSOP-II-54_22.2x10.16mm_P0.8mm | C62246 | W9825G6KH-6
U601 | 1 | LMV321 | Package_TO_SOT_SMD:SOT-23-5 | C7972 | LMV321IDBVR
U602 | 1 | TL432DBZ | Package_TO_SOT_SMD:SOT-23 | C5184435 | TL432
U603,U1002 | 2 | THS4521IDGK | Package_SO:VSSOP-8_3x3mm_P0.65mm | C170157 | THS4521IDGKR
U701 | 1 | AMS1117-3.3 | Package_TO_SOT_SMD:SOT-223-3_TabPin2 | C6186 | AMS1117-3.3
Y201 | 1 | 8MHz | Crystal:Crystal_SMD_5032-2Pin_5.0x3.2mm | C115962 | X50328MSB2GI

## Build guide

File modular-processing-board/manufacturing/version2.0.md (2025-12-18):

# Schematic fixes
- Make sure the boot0 pin is pulled down, and there's a button to pull it high instead of having to manually connect a wire.

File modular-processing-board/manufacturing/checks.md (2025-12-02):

 # Checks
 - Are traces not wobbly?
	- Often times when traces are drawn around vias they end up being smeared out
- Are all connected zones merged? 
	- Kicad doesn't automatically 2 identical zones that are side by side together unless they actually overlap. To be on the safe side, make sure to merge all the zones

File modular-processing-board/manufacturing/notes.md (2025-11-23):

- Exporting Gerbers + Drill-files from kicad9: https://jlcpcb.com/help/article/how-to-generate-gerber-and-drill-files-in-kicad-9
- BOM + centroid generation: https://jlcpcb.com/help/article/How-to-generate-the-BOM-and-Centroid-file-from-KiCAD

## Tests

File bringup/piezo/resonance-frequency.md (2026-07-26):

# Questions
## How does one determine the resonance frequency?

Likely one can simply wire a coax with 2 wires to the piezo, and then connect it to a regulator multimeter, this would allow
- Series static capacitance measurement

Having it connected to a VNA can after a sweep give you
- The resonance frequency (frequency where the reactance is 0, and everything is purely converted into mechanical waves).

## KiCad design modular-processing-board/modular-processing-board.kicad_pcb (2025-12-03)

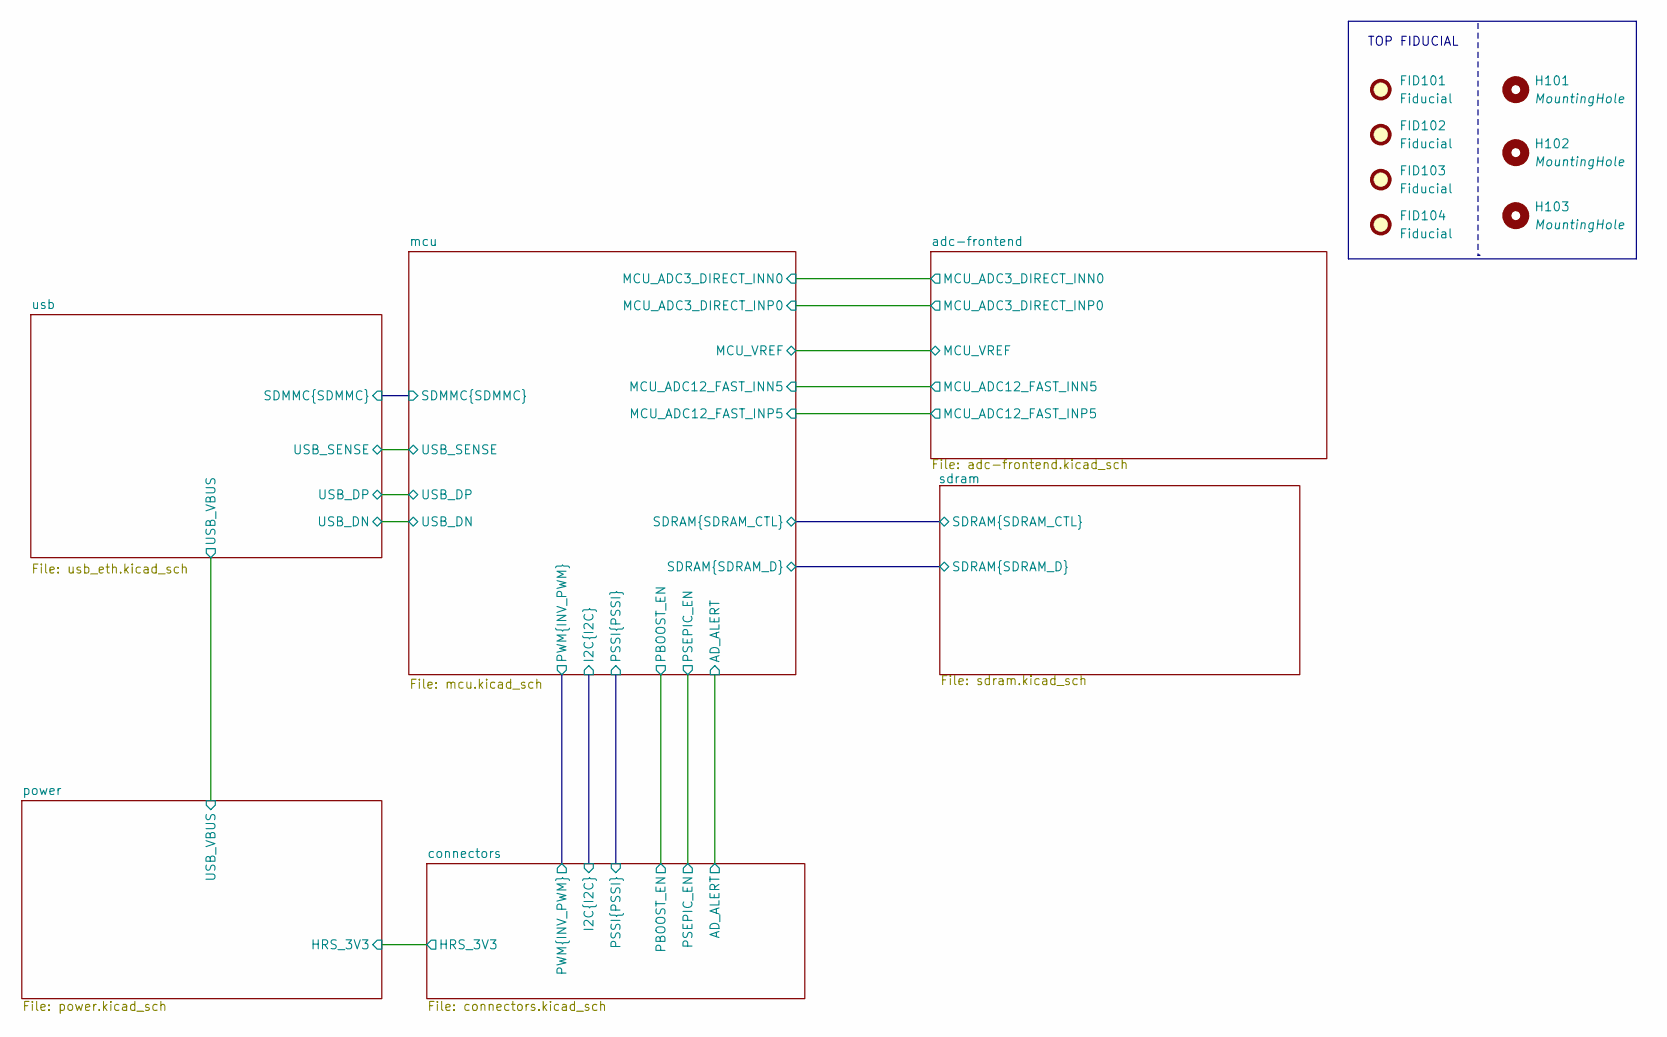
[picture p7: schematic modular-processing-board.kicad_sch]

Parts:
FID101, FID102, FID103, FID104: Fiducial; Fiducial_1mm_Mask2mm
H101, H102, H103: MountingHole; ToolingHole_1.152mm

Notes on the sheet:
TOP FIDUCIAL

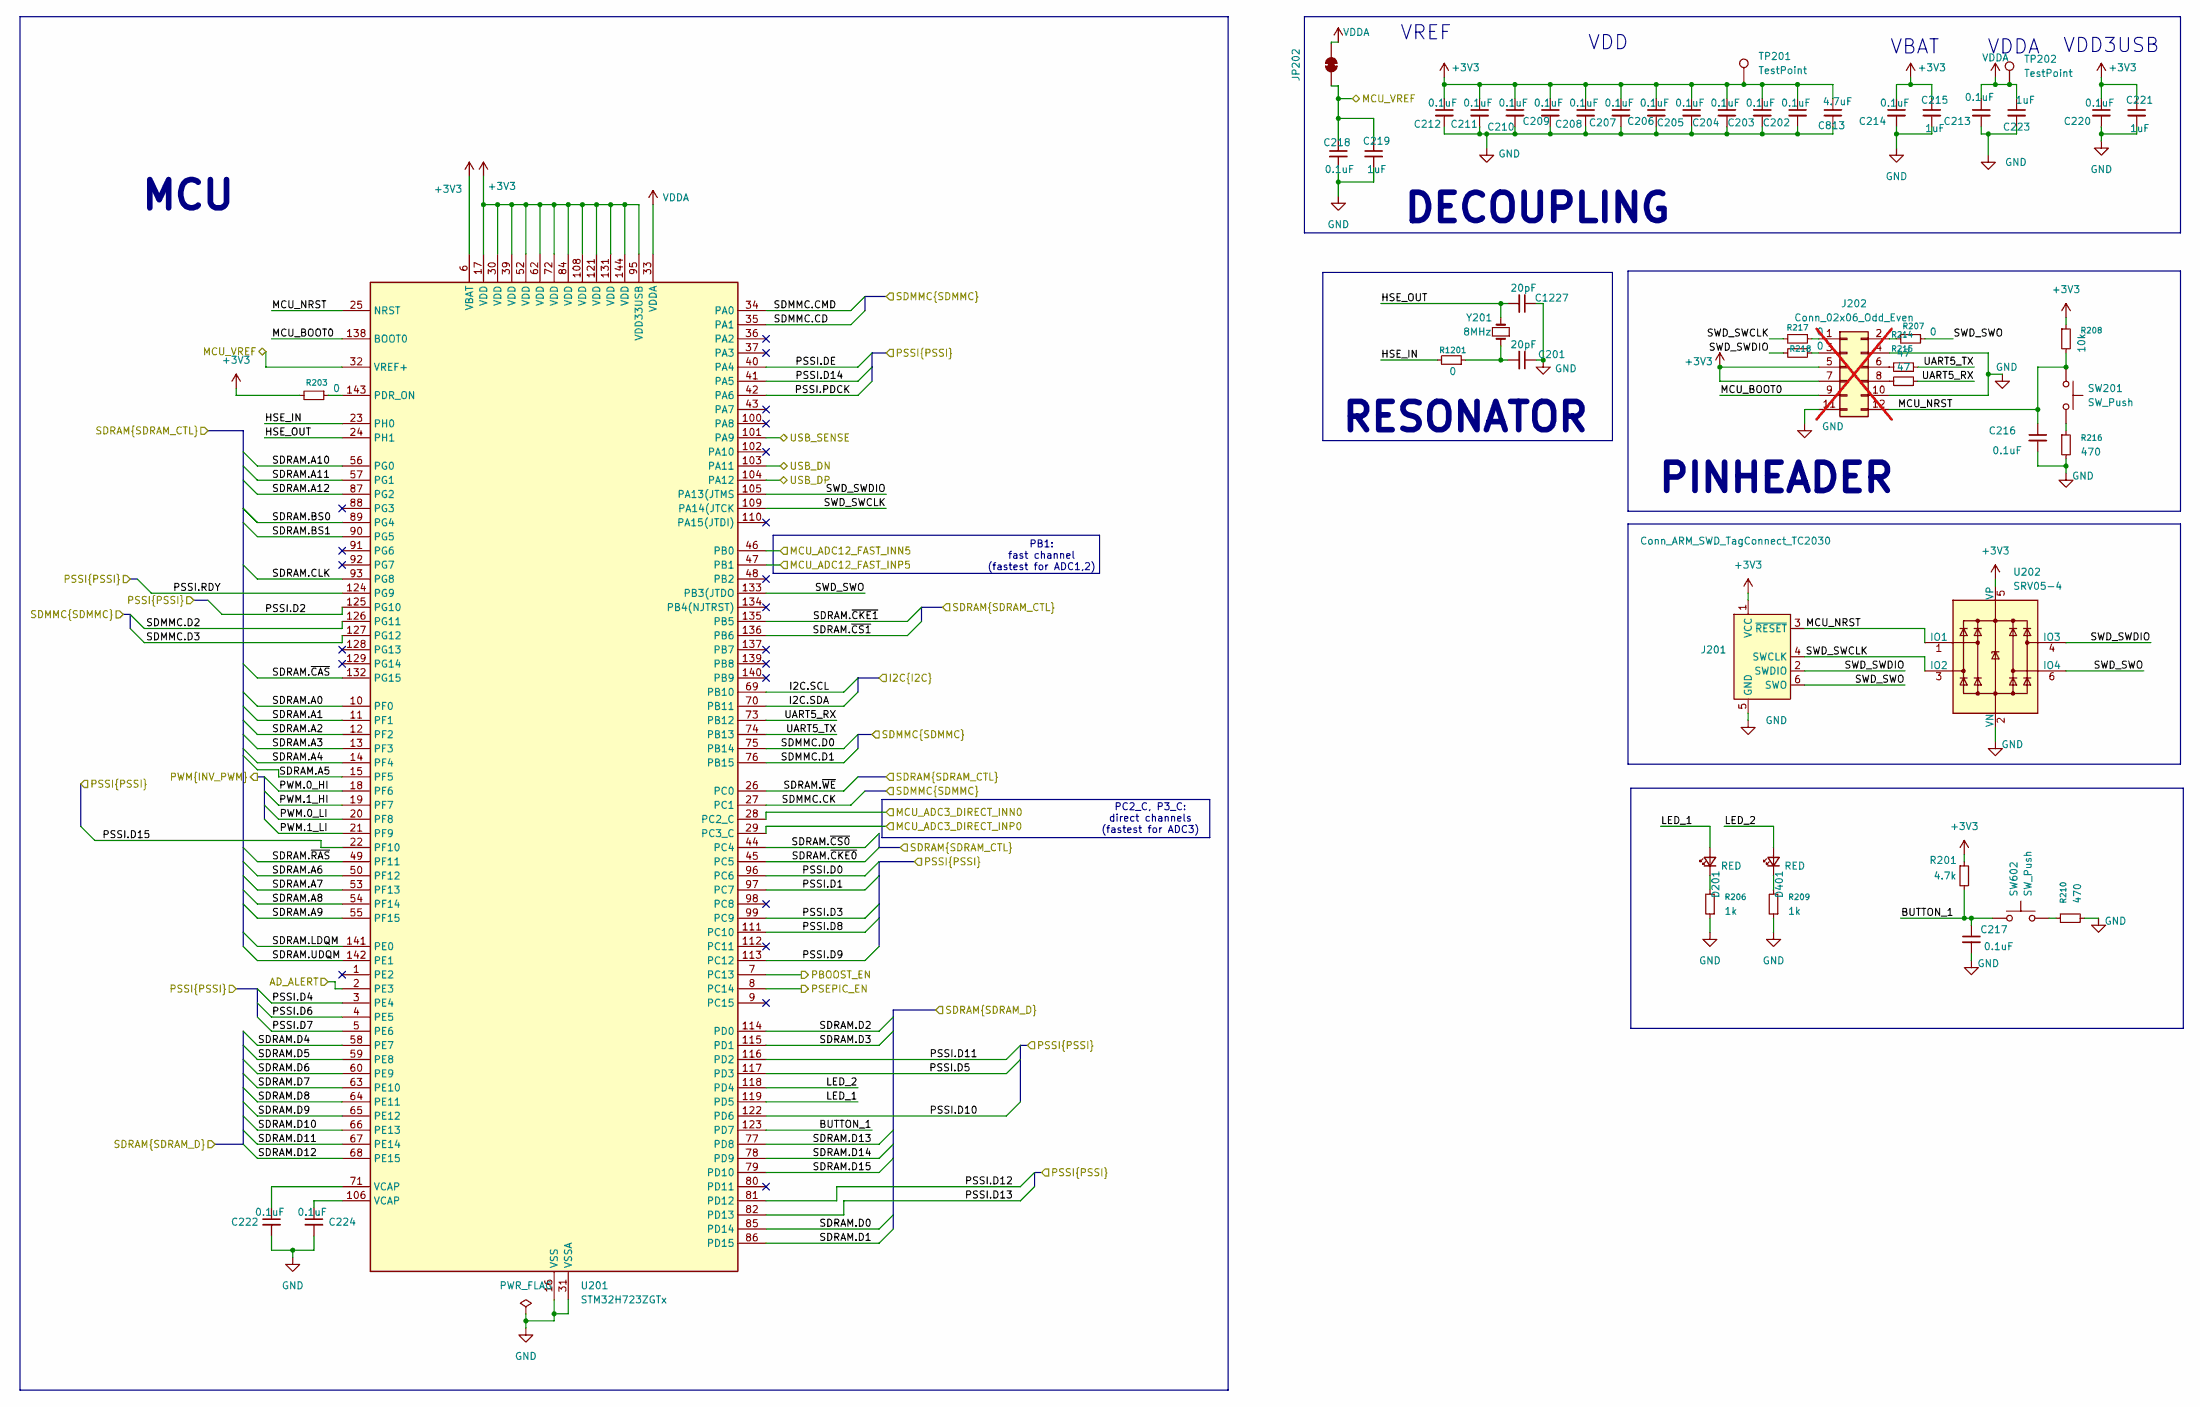
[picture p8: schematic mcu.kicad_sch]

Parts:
C201, C1227: 20pF; C_0402_1005Metric; MPN 0402CG200J500NT
C202, C203, C204, C205, C206, C207, C208, C209, C210, C211, C212, C213, C214, C216, C217, C218, C220, C222, C224: 0.1uF; C_0402_1005Metric; MPN CL05B104KB54PNC
C215, C219, C221, C223: 1uF; C_0805_2012Metric; MPN CL21B105KBFNNNE
C813: 4.7uF; C_0402_1005Metric; MPN CL05A475MP5NRNC
D201, D401: RED; LED_0603_1608Metric; MPN KT-0603R
J201: Conn_ARM_SWD_TagConnect_TC2030; Tag-Connect_TC2030-IDC-FP_2x03_P1.27mm_Vertical
J202: Conn_02x06_Odd_Even; PinHeader_2x06_P2.54mm_Vertical; not fitted
JP202: SolderJumper_2_Bridged; SolderJumper-2_P1.3mm_Bridged2Bar_Pad1.0x1.5mm
R201: 4.7k; R_0402_1005Metric; MPN 0402WGF4701TCE
R203, R207, R217, R218, R1201: 0; R_0603_1608Metric; MPN 0603WAF0000T5E
R206, R209: 1k; R_0402_1005Metric; MPN 0402WGF1001TCE
R208: 10k; R_0603_1608Metric; MPN 0603WAF1002T5E
R210, R216: 470; R_0402_1005Metric; MPN 0402WGF4700TCE
R214, R215: 47; R_0603_1608Metric; MPN 0603WAF470JT5E
SW201, SW602: SW_Push; SW_TS-1088-AR02016; MPN TS-1088-AR02016
TP201, TP202: TestPoint; PinSocket_1x01_P1.27mm_Vertical
U201: STM32H723ZGTx; LQFP-144_20x20mm_P0.5mm; MPN STM32H723ZGT6
U202: SRV05-4; SOT-23-6; MPN SRV05-4A
Y201: 8MHz; Crystal_SMD_5032-2Pin_5.0x3.2mm; MPN X50328MSB2GI

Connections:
+3V3: C202.1, C203.1, C204.1, C205.1, C206.1, C207.1, C208.1, C209.1, C210.1, C211.1, C212.1, C214.1, C215.1, C220.1, C221.1, C813.1, J201.1 (VCC), J202.5, J202.7, R201.1, R203.2, R208.1, TP201.1, U201.6 (VBAT), U201.17 (VDD), U201.30 (VDD), U201.39 (VDD), U201.52 (VDD), U201.62 (VDD), U201.72 (VDD), U201.84 (VDD), U201.95 (VDD33USB), U201.108 (VDD), U201.121 (VDD), U201.131 (VDD), U201.144 (VDD), U202.5 (VP); also elsewhere on the board
/adc-frontend/MCU_ADC3_DIRECT_INN0: U201.28 (PC2_C); also elsewhere on the board
/adc-frontend/MCU_ADC3_DIRECT_INP0: U201.29 (PC3_C); also elsewhere on the board
/adc-frontend/MCU_ADC12_FAST_INN5: U201.46 (PB0); also elsewhere on the board
/adc-frontend/MCU_ADC12_FAST_INP5: U201.47 (PB1); also elsewhere on the board
/adc-frontend/MCU_VREF: C218.1, C219.1, JP202.1 (A), U201.32 (VREF+); also elsewhere on the board
/connectors/AD_ALERT: U201.2 (PE3); also elsewhere on the board
/connectors/I2C.SCL: U201.69 (PB10); also elsewhere on the board
/connectors/I2C.SDA: U201.70 (PB11); also elsewhere on the board
/connectors/PBOOST_EN: U201.7 (PC13); also elsewhere on the board
/connectors/PSEPIC_EN: U201.8 (PC14); also elsewhere on the board
/connectors/PSSI.D0: U201.96 (PC6); also elsewhere on the board
/connectors/PSSI.D1: U201.97 (PC7); also elsewhere on the board
/connectors/PSSI.D2: U201.125 (PG10); also elsewhere on the board
/connectors/PSSI.D3: U201.99 (PC9); also elsewhere on the board
/connectors/PSSI.D4: U201.3 (PE4); also elsewhere on the board
/connectors/PSSI.D5: U201.117 (PD3); also elsewhere on the board
/connectors/PSSI.D6: U201.4 (PE5); also elsewhere on the board
/connectors/PSSI.D7: U201.5 (PE6); also elsewhere on the board
/connectors/PSSI.D8: U201.111 (PC10); also elsewhere on the board
/connectors/PSSI.D9: U201.113 (PC12); also elsewhere on the board
/connectors/PSSI.D10: U201.122 (PD6); also elsewhere on the board
/connectors/PSSI.D11: U201.116 (PD2); also elsewhere on the board
/connectors/PSSI.D12: U201.81 (PD12); also elsewhere on the board
/connectors/PSSI.D13: U201.82 (PD13); also elsewhere on the board
/connectors/PSSI.D14: U201.41 (PA5); also elsewhere on the board
/connectors/PSSI.D15: U201.22 (PF10); also elsewhere on the board
/connectors/PSSI.DE: U201.40 (PA4); also elsewhere on the board
/connectors/PSSI.PDCK: U201.42 (PA6); also elsewhere on the board
/connectors/PSSI.RDY: U201.124 (PG9); also elsewhere on the board
/connectors/PWM.0_HI: U201.18 (PF6); also elsewhere on the board
/connectors/PWM.0_LI: U201.20 (PF8); also elsewhere on the board
/connectors/PWM.1_HI: U201.19 (PF7); also elsewhere on the board
/connectors/PWM.1_LI: U201.21 (PF9); also elsewhere on the board
/mcu/BUTTON_1: C217.1, R201.2, SW602.1, U201.123 (PD7)
/mcu/HSE_IN: R1201.2, U201.23 (PH0)
/mcu/HSE_OUT: C1227.2, U201.24 (PH1), Y201.2
/mcu/LED_1: D201.2 (A), U201.119 (PD5)
/mcu/LED_2: D401.2 (A), U201.118 (PD4)
/mcu/MCU_BOOT0: J202.9, U201.138 (BOOT0)
/mcu/MCU_NRST: C216.1, J201.3 (~RESET), J202.12, R208.2, SW201.1, U201.25 (NRST), U202.1 (IO1)
/mcu/SDMMC.CD: U201.35 (PA1); also elsewhere on the board
/mcu/SDMMC.CK: U201.27 (PC1); also elsewhere on the board
/mcu/SDMMC.CMD: U201.34 (PA0); also elsewhere on the board
/mcu/SDMMC.D0: U201.75 (PB14); also elsewhere on the board
/mcu/SDMMC.D1: U201.76 (PB15); also elsewhere on the board
/mcu/SDMMC.D2: U201.126 (PG11); also elsewhere on the board
/mcu/SDMMC.D3: U201.127 (PG12); also elsewhere on the board
/mcu/SDRAM.A0: U201.10 (PF0); also elsewhere on the board
/mcu/SDRAM.A1: U201.11 (PF1); also elsewhere on the board
/mcu/SDRAM.A2: U201.12 (PF2); also elsewhere on the board
/mcu/SDRAM.A3: U201.13 (PF3); also elsewhere on the board
/mcu/SDRAM.A4: U201.14 (PF4); also elsewhere on the board
/mcu/SDRAM.A5: U201.15 (PF5); also elsewhere on the board
/mcu/SDRAM.A6: U201.50 (PF12); also elsewhere on the board
/mcu/SDRAM.A7: U201.53 (PF13); also elsewhere on the board
/mcu/SDRAM.A8: U201.54 (PF14); also elsewhere on the board
/mcu/SDRAM.A9: U201.55 (PF15); also elsewhere on the board
/mcu/SDRAM.A10: U201.56 (PG0); also elsewhere on the board
/mcu/SDRAM.A11: U201.57 (PG1); also elsewhere on the board
/mcu/SDRAM.A12: U201.87 (PG2); also elsewhere on the board
/mcu/SDRAM.BS0: U201.89 (PG4); also elsewhere on the board
/mcu/SDRAM.BS1: U201.90 (PG5); also elsewhere on the board
/mcu/SDRAM.CLK: U201.93 (PG8); also elsewhere on the board
/mcu/SDRAM.D0: U201.85 (PD14); also elsewhere on the board
/mcu/SDRAM.D1: U201.86 (PD15); also elsewhere on the board
/mcu/SDRAM.D2: U201.114 (PD0); also elsewhere on the board
/mcu/SDRAM.D3: U201.115 (PD1); also elsewhere on the board
/mcu/SDRAM.D4: U201.58 (PE7); also elsewhere on the board
/mcu/SDRAM.D5: U201.59 (PE8); also elsewhere on the board
/mcu/SDRAM.D6: U201.60 (PE9); also elsewhere on the board
/mcu/SDRAM.D7: U201.63 (PE10); also elsewhere on the board
/mcu/SDRAM.D8: U201.64 (PE11); also elsewhere on the board
/mcu/SDRAM.D9: U201.65 (PE12); also elsewhere on the board
/mcu/SDRAM.D10: U201.66 (PE13); also elsewhere on the board
/mcu/SDRAM.D11: U201.67 (PE14); also elsewhere on the board
/mcu/SDRAM.D12: U201.68 (PE15); also elsewhere on the board
/mcu/SDRAM.D13: U201.77 (PD8); also elsewhere on the board
/mcu/SDRAM.D14: U201.78 (PD9); also elsewhere on the board
/mcu/SDRAM.D15: U201.79 (PD10); also elsewhere on the board
/mcu/SDRAM.LDQM: U201.141 (PE0); also elsewhere on the board
/mcu/SDRAM.UDQM: U201.142 (PE1); also elsewhere on the board
/mcu/SDRAM.~CAS: U201.132 (PG15); also elsewhere on the board
/mcu/SDRAM.~CKE0: U201.45 (PC5); also elsewhere on the board
/mcu/SDRAM.~CKE1: U201.135 (PB5); also elsewhere on the board
/mcu/SDRAM.~CS0: U201.44 (PC4); also elsewhere on the board
/mcu/SDRAM.~CS1: U201.136 (PB6); also elsewhere on the board
/mcu/SDRAM.~RAS: U201.49 (PF11); also elsewhere on the board
/mcu/SDRAM.~WE: U201.26 (PC0); also elsewhere on the board
/mcu/SWD_SWCLK: J201.4 (SWCLK), R217.2, U201.109 (PA14(JTCK), U202.3 (IO2)
/mcu/SWD_SWDIO: J201.2 (SWDIO), R218.2, U201.105 (PA13(JTMS), U202.4 (IO3)
/mcu/SWD_SWO: J201.6 (SWO), R207.1, U201.133 (PB3(JTDO), U202.6 (IO4)
/mcu/UART5_RX: R215.1, U201.73 (PB12)
/mcu/UART5_TX: R214.1, U201.74 (PB13)
/mcu/USB_DN: U201.103 (PA11); also elsewhere on the board
/mcu/USB_DP: U201.104 (PA12); also elsewhere on the board
/mcu/USB_SENSE: U201.101 (PA9); also elsewhere on the board
GND: C201.1, C202.2, C203.2, C204.2, C205.2, C206.2, C207.2, C208.2, C209.2, C210.2, C211.2, C212.2, C213.2, C214.2, C215.2, C216.2, C217.2, C218.2, C219.2, C220.2, C221.2, C222.2, C223.2, C224.2, C813.2, C1227.1, J201.5 (GND), J202.4, J202.10, J202.11, R206.1, R209.1, R210.2, R216.2, U201.16 (VSS), U201.31 (VSSA), U201.38 (VSS), U201.51 (VSS), U201.61 (VSS), U201.83 (VSS), U201.94 (VSS), U201.107 (VSS), U201.120 (VSS), U201.130 (VSS), U202.2 (VN); also elsewhere on the board
unnamed: C201.2, R1201.1, Y201.1
unnamed: C222.1, U201.71 (VCAP)
unnamed: C224.1, U201.106 (VCAP)
unnamed: D201.1 (K), R206.2
unnamed: D401.1 (K), R209.2
unnamed: J202.1, R217.1
unnamed: J202.2, R207.2
unnamed: J202.3, R218.1
unnamed: J202.6, R214.2
unnamed: J202.8, R215.2
unnamed: R210.1, SW602.2
unnamed: R216.1, SW201.2
unnamed: R203.1, U201.143 (PDR_ON)
VDDA: C213.1, C223.1, JP202.2 (B), TP202.1, U201.33 (VDDA); also elsewhere on the board

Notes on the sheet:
PINHEADER
PB1: fast channel (fastest for ADC1,2)
MCU
PC2_C, P3_C: direct channels (fastest for ADC3)
VDD3USB
VDD
RESONATOR
VREF
DECOUPLING
VBAT
VDDA

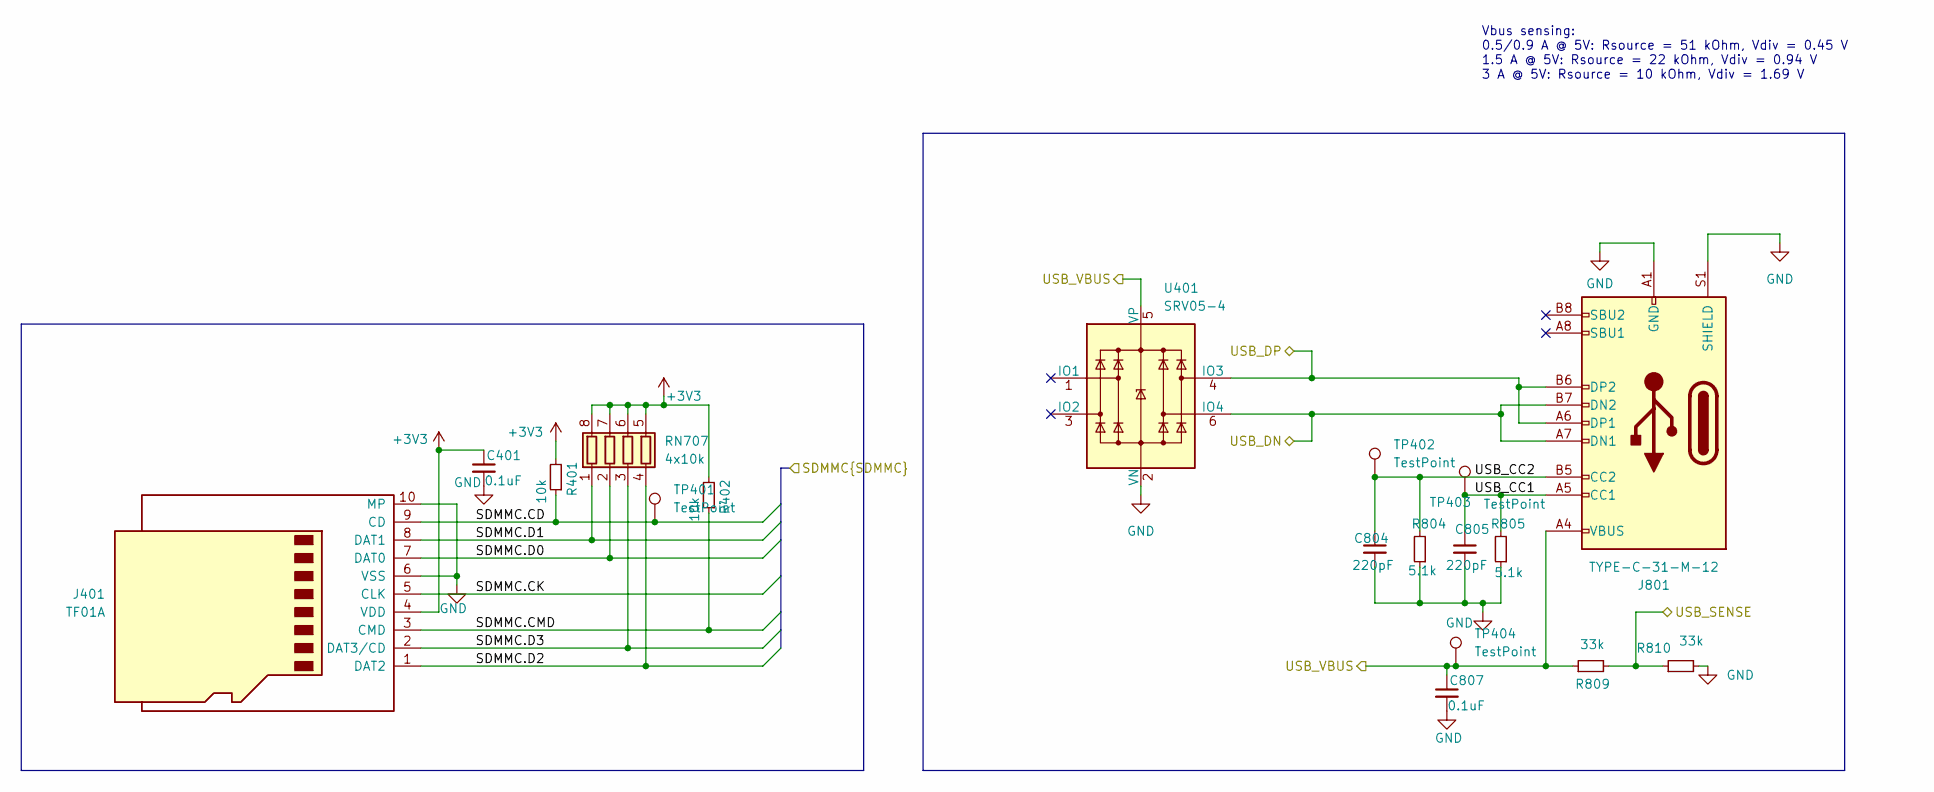
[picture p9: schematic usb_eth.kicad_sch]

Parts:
C401, C807: 0.1uF; C_0402_1005Metric; MPN CL05B104KB54PNC
C804, C805: 220pF; C_0402_1005Metric; MPN 0402B221K500NT
J401: TF01A; MPN TF-01A
J801: TYPE-C-31-M-12; USB_C_Receptacle_HRO_TYPE-C-31-M-12; MPN TYPE-C-31-M-12
R401, R402: 10k; R_0603_1608Metric; MPN 0603WAF1002T5E
R804, R805: 5.1k; R_0603_1608Metric; MPN 0603WAF5101T5E
R809, R810: 33k; R_0603_1608Metric; MPN 0603WAF3302T5E
RN707: 4x10k; R_Array_Convex_4x0603; MPN 4D03WGJ0103T5E
TP401, TP402, TP403, TP404: TestPoint; PinSocket_1x01_P1.27mm_Vertical
U401: SRV05-4; SOT-23-6; MPN SRV05-4A

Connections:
+3V3: C401.1, J401.4 (VDD), R401.2, R402.2, RN707.5 (R4.2), RN707.6 (R3.2), RN707.7 (R2.2), RN707.8 (R1.2); also elsewhere on the board
/mcu/SDMMC.CD: J401.9 (CD), R401.1, TP401.1; also elsewhere on the board
/mcu/SDMMC.CK: J401.5 (CLK); also elsewhere on the board
/mcu/SDMMC.CMD: J401.3 (CMD), R402.1; also elsewhere on the board
/mcu/SDMMC.D0: J401.7 (DAT0), RN707.2 (R2.1); also elsewhere on the board
/mcu/SDMMC.D1: J401.8 (DAT1), RN707.1 (R1.1); also elsewhere on the board
/mcu/SDMMC.D2: J401.1 (DAT2), RN707.4 (R4.1); also elsewhere on the board
/mcu/SDMMC.D3: J401.2 (DAT3/CD), RN707.3 (R3.1); also elsewhere on the board
/mcu/USB_DN: J801.A7 (DN1), J801.B7 (DN2), U401.6 (IO4); also elsewhere on the board
/mcu/USB_DP: J801.A6 (DP1), J801.B6 (DP2), U401.4 (IO3); also elsewhere on the board
/mcu/USB_SENSE: R809.2, R810.1; also elsewhere on the board
/power/USB_VBUS: C807.1, J801.A4 (VBUS), J801.A9 (VBUS), J801.B4 (VBUS), J801.B9 (VBUS), R809.1, TP404.1, U401.5 (VP); also elsewhere on the board
/usb/USB_CC1: C805.1, J801.A5 (CC1), R805.2, TP403.1
/usb/USB_CC2: C804.1, J801.B5 (CC2), R804.2, TP402.1
GND: C401.2, C804.2, C805.2, C807.2, J401.6 (VSS), J401.10 (MP), J801.A1 (GND), J801.A12 (GND), J801.B1 (GND), J801.B12 (GND), J801.S1 (SHIELD), R804.1, R805.1, R810.2, U401.2 (VN); also elsewhere on the board

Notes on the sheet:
Vbus sensing: 0.5/0.9 A @ 5V: Rsource = 51 kOhm, Vdiv = 0.45 V 1.5 A @ 5V: Rsource = 22 kOhm, Vdiv = 0.94 V 3 A @ 5V: Rsource = 10 kOhm, Vdiv = 1.69 V

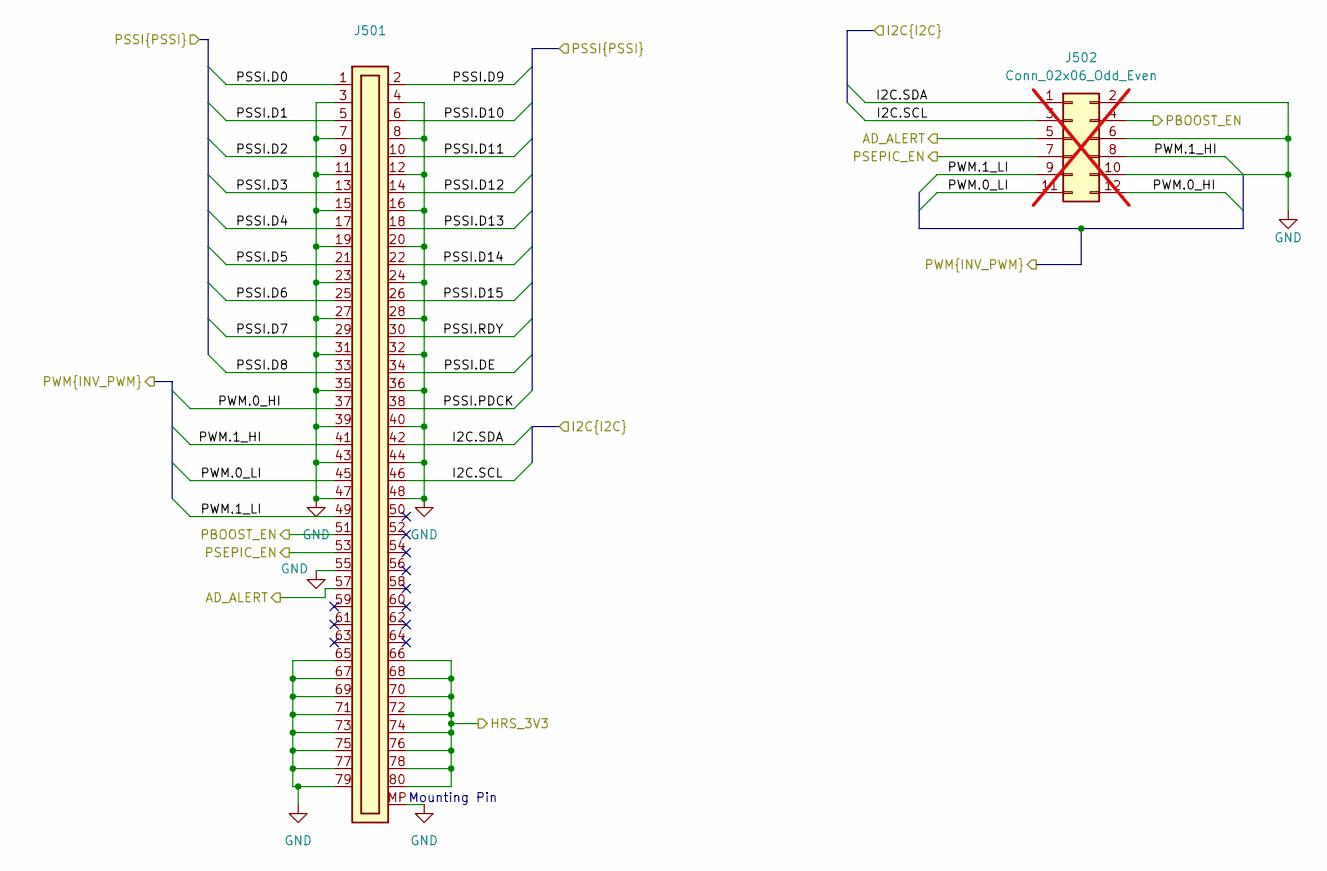
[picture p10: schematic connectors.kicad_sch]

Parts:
J501: Plug_Hirose_DF40_2x40_DF40C-80DP-0.4V; HRS_DF40C-80DP-0.4V(51); MPN DF40C-80DP-0.4V(51)
J502: Conn_02x06_Odd_Even; PinSocket_2x06_P2.54mm_Vertical; not fitted

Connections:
/connectors/AD_ALERT: J501.57, J502.5; also elsewhere on the board
/connectors/HRS_3V3: J501.66, J501.68, J501.70, J501.72, J501.74, J501.76, J501.78, J501.80; also elsewhere on the board
/connectors/I2C.SCL: J501.46, J502.3; also elsewhere on the board
/connectors/I2C.SDA: J501.42, J502.1; also elsewhere on the board
/connectors/PBOOST_EN: J501.51, J502.4; also elsewhere on the board
/connectors/PSEPIC_EN: J501.53, J502.7; also elsewhere on the board
/connectors/PSSI.D0: J501.1; also elsewhere on the board
/connectors/PSSI.D1: J501.5; also elsewhere on the board
/connectors/PSSI.D2: J501.9; also elsewhere on the board
/connectors/PSSI.D3: J501.13; also elsewhere on the board
/connectors/PSSI.D4: J501.17; also elsewhere on the board
/connectors/PSSI.D5: J501.21; also elsewhere on the board
/connectors/PSSI.D6: J501.25; also elsewhere on the board
/connectors/PSSI.D7: J501.29; also elsewhere on the board
/connectors/PSSI.D8: J501.33; also elsewhere on the board
/connectors/PSSI.D9: J501.2; also elsewhere on the board
/connectors/PSSI.D10: J501.6; also elsewhere on the board
/connectors/PSSI.D11: J501.10; also elsewhere on the board
/connectors/PSSI.D12: J501.14; also elsewhere on the board
/connectors/PSSI.D13: J501.18; also elsewhere on the board
/connectors/PSSI.D14: J501.22; also elsewhere on the board
/connectors/PSSI.D15: J501.26; also elsewhere on the board
/connectors/PSSI.DE: J501.34; also elsewhere on the board
/connectors/PSSI.PDCK: J501.38; also elsewhere on the board
/connectors/PSSI.RDY: J501.30; also elsewhere on the board
/connectors/PWM.0_HI: J501.37, J502.12; also elsewhere on the board
/connectors/PWM.0_LI: J501.45, J502.11; also elsewhere on the board
/connectors/PWM.1_HI: J501.41, J502.8; also elsewhere on the board
/connectors/PWM.1_LI: J501.49, J502.9; also elsewhere on the board
GND: J501.3, J501.4, J501.7, J501.8, J501.11, J501.12, J501.15, J501.16, J501.19, J501.20, J501.23, J501.24, J501.27, J501.28, J501.31, J501.32, J501.35, J501.36, J501.39, J501.40, J501.43, J501.44, J501.47, J501.48, J501.55, J501.65, J501.67, J501.69, J501.71, J501.73, J501.75, J501.77, J501.79, J501.MP, J502.2, J502.6, J502.10; also elsewhere on the board

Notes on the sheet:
Mounting Pin

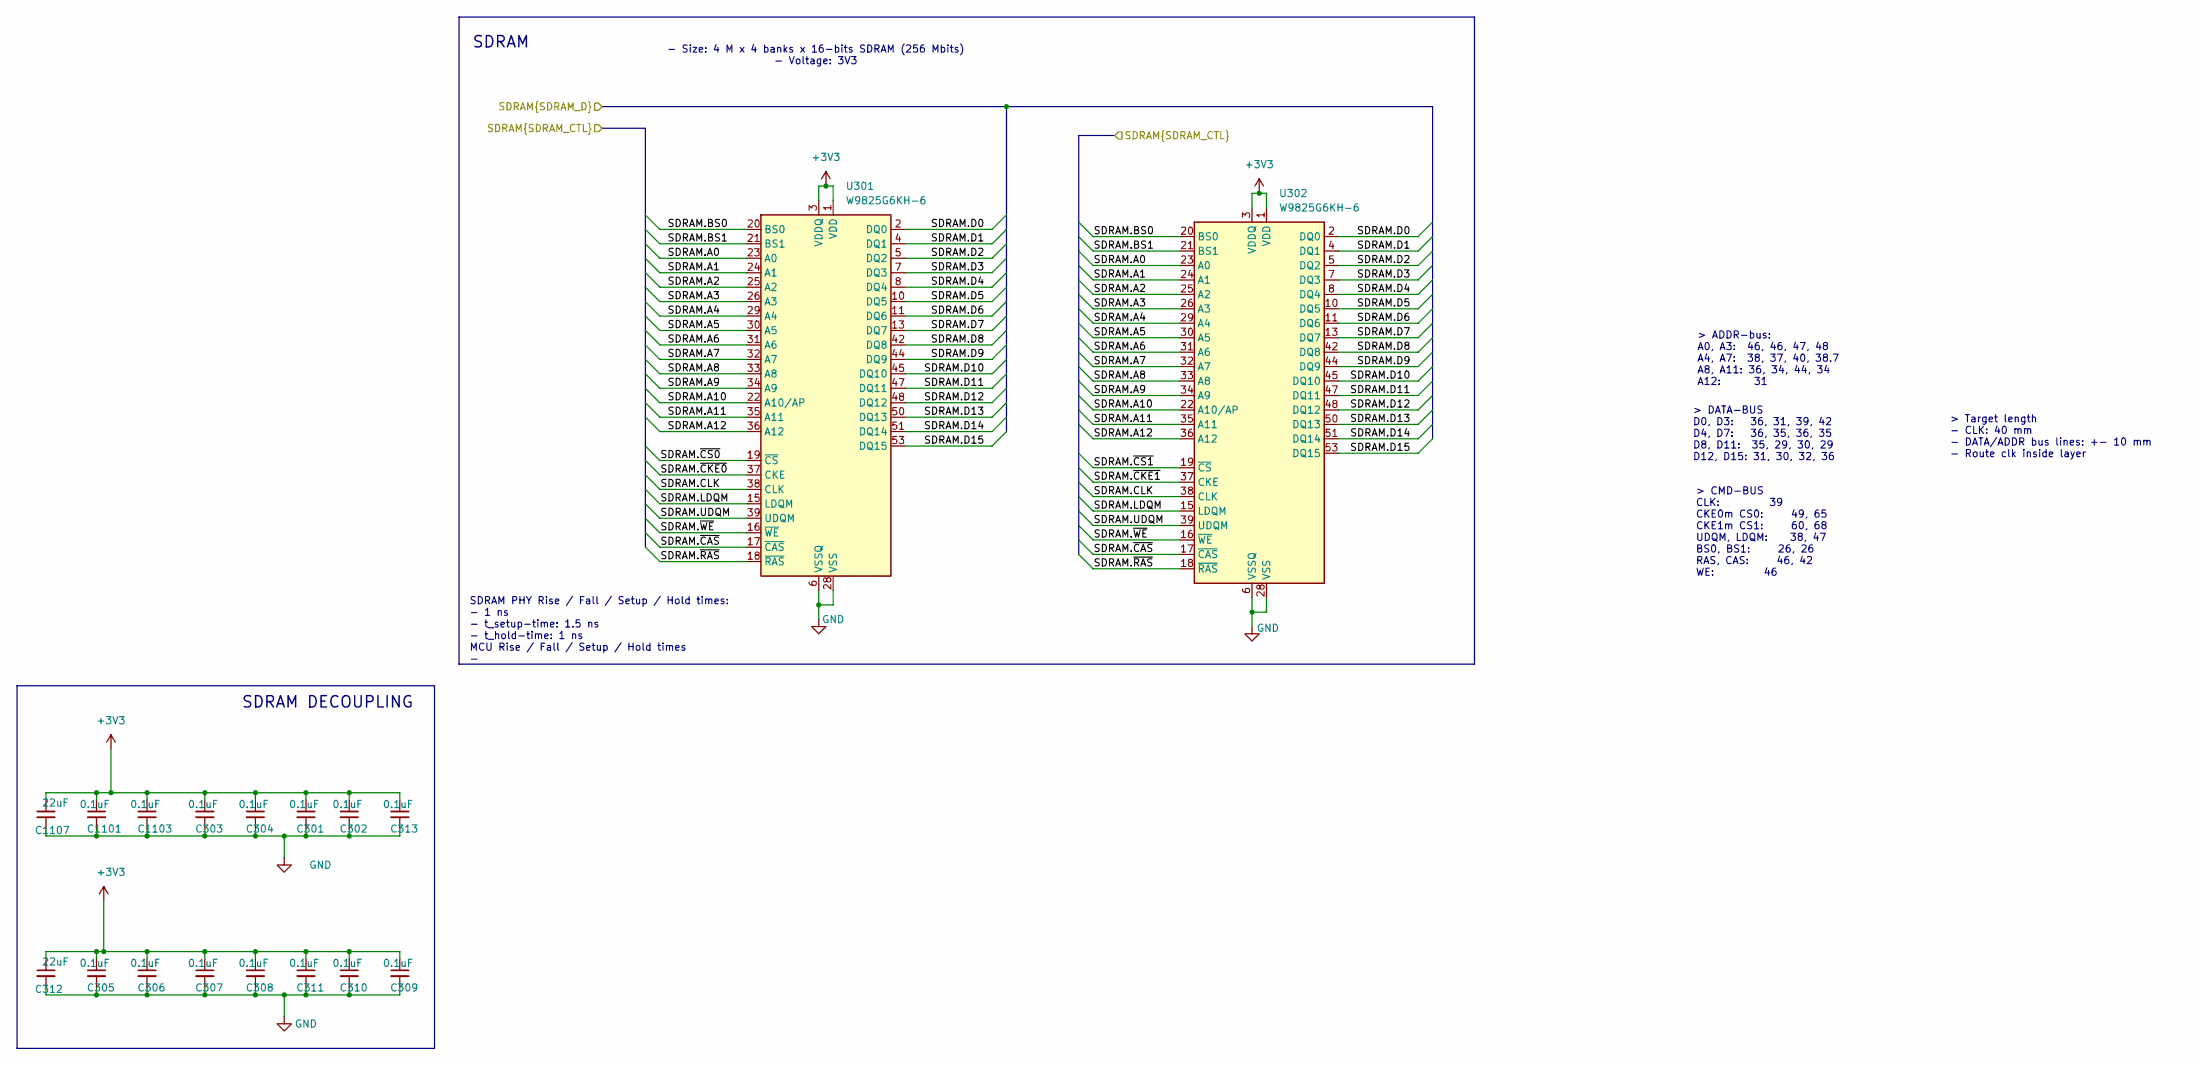
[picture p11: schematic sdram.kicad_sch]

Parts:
C301, C302, C303, C304, C305, C306, C307, C308, C309, C310, C311, C313, C1101, C1103: 0.1uF; C_0402_1005Metric; MPN CL05B104KB54PNC
C312, C1107: 22uF; C_0603_1608Metric; MPN CL10A226MQ8NRNC
U301, U302: W9825G6KH-6; TSOP-II-54_22.2x10.16mm_P0.8mm; MPN W9825G6KH-6

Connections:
+3V3: C301.1, C302.1, C303.1, C304.1, C305.1, C306.1, C307.1, C308.1, C309.1, C310.1, C311.1, C312.1, C313.1, C1101.1, C1103.1, C1107.1, U301.1 (VDD), U301.3 (VDDQ), U301.9 (VDDQ), U301.14 (VDD), U301.27 (VDD), U301.43 (VDDQ), U301.49 (VDDQ), U302.1 (VDD), U302.3 (VDDQ), U302.9 (VDDQ), U302.14 (VDD), U302.27 (VDD), U302.43 (VDDQ), U302.49 (VDDQ); also elsewhere on the board
/mcu/SDRAM.A0: U301.23 (A0), U302.23 (A0); also elsewhere on the board
/mcu/SDRAM.A1: U301.24 (A1), U302.24 (A1); also elsewhere on the board
/mcu/SDRAM.A2: U301.25 (A2), U302.25 (A2); also elsewhere on the board
/mcu/SDRAM.A3: U301.26 (A3), U302.26 (A3); also elsewhere on the board
/mcu/SDRAM.A4: U301.29 (A4), U302.29 (A4); also elsewhere on the board
/mcu/SDRAM.A5: U301.30 (A5), U302.30 (A5); also elsewhere on the board
/mcu/SDRAM.A6: U301.31 (A6), U302.31 (A6); also elsewhere on the board
/mcu/SDRAM.A7: U301.32 (A7), U302.32 (A7); also elsewhere on the board
/mcu/SDRAM.A8: U301.33 (A8), U302.33 (A8); also elsewhere on the board
/mcu/SDRAM.A9: U301.34 (A9), U302.34 (A9); also elsewhere on the board
/mcu/SDRAM.A10: U301.22 (A10/AP), U302.22 (A10/AP); also elsewhere on the board
/mcu/SDRAM.A11: U301.35 (A11), U302.35 (A11); also elsewhere on the board
/mcu/SDRAM.A12: U301.36 (A12), U302.36 (A12); also elsewhere on the board
/mcu/SDRAM.BS0: U301.20 (BS0), U302.20 (BS0); also elsewhere on the board
/mcu/SDRAM.BS1: U301.21 (BS1), U302.21 (BS1); also elsewhere on the board
/mcu/SDRAM.CLK: U301.38 (CLK), U302.38 (CLK); also elsewhere on the board
/mcu/SDRAM.D0: U301.2 (DQ0), U302.2 (DQ0); also elsewhere on the board
/mcu/SDRAM.D1: U301.4 (DQ1), U302.4 (DQ1); also elsewhere on the board
/mcu/SDRAM.D2: U301.5 (DQ2), U302.5 (DQ2); also elsewhere on the board
/mcu/SDRAM.D3: U301.7 (DQ3), U302.7 (DQ3); also elsewhere on the board
/mcu/SDRAM.D4: U301.8 (DQ4), U302.8 (DQ4); also elsewhere on the board
/mcu/SDRAM.D5: U301.10 (DQ5), U302.10 (DQ5); also elsewhere on the board
/mcu/SDRAM.D6: U301.11 (DQ6), U302.11 (DQ6); also elsewhere on the board
/mcu/SDRAM.D7: U301.13 (DQ7), U302.13 (DQ7); also elsewhere on the board
/mcu/SDRAM.D8: U301.42 (DQ8), U302.42 (DQ8); also elsewhere on the board
/mcu/SDRAM.D9: U301.44 (DQ9), U302.44 (DQ9); also elsewhere on the board
/mcu/SDRAM.D10: U301.45 (DQ10), U302.45 (DQ10); also elsewhere on the board
/mcu/SDRAM.D11: U301.47 (DQ11), U302.47 (DQ11); also elsewhere on the board
/mcu/SDRAM.D12: U301.48 (DQ12), U302.48 (DQ12); also elsewhere on the board
/mcu/SDRAM.D13: U301.50 (DQ13), U302.50 (DQ13); also elsewhere on the board
/mcu/SDRAM.D14: U301.51 (DQ14), U302.51 (DQ14); also elsewhere on the board
/mcu/SDRAM.D15: U301.53 (DQ15), U302.53 (DQ15); also elsewhere on the board
/mcu/SDRAM.LDQM: U301.15 (LDQM), U302.15 (LDQM); also elsewhere on the board
/mcu/SDRAM.UDQM: U301.39 (UDQM), U302.39 (UDQM); also elsewhere on the board
/mcu/SDRAM.~CAS: U301.17 (~CAS), U302.17 (~CAS); also elsewhere on the board
/mcu/SDRAM.~CKE0: U301.37 (CKE); also elsewhere on the board
/mcu/SDRAM.~CKE1: U302.37 (CKE); also elsewhere on the board
/mcu/SDRAM.~CS0: U301.19 (~CS); also elsewhere on the board
/mcu/SDRAM.~CS1: U302.19 (~CS); also elsewhere on the board
/mcu/SDRAM.~RAS: U301.18 (~RAS), U302.18 (~RAS); also elsewhere on the board
/mcu/SDRAM.~WE: U301.16 (~WE), U302.16 (~WE); also elsewhere on the board
GND: C301.2, C302.2, C303.2, C304.2, C305.2, C306.2, C307.2, C308.2, C309.2, C310.2, C311.2, C312.2, C313.2, C1101.2, C1103.2, C1107.2, U301.6 (VSSQ), U301.12 (VSSQ), U301.28 (VSS), U301.41 (VSS), U301.46 (VSSQ), U301.52 (VSSQ), U301.54 (VSS), U302.6 (VSSQ), U302.12 (VSSQ), U302.28 (VSS), U302.41 (VSS), U302.46 (VSSQ), U302.52 (VSSQ), U302.54 (VSS); also elsewhere on the board

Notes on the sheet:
> DATA-BUS D0, D3: 36, 31, 39, 42 D4, D7: 36, 35, 36, 35 D8, D11: 35, 29, 30, 29 D12, D15: 31, 30, 32, 36
> Target length - CLK: 40 mm - DATA/ADDR bus lines: +- 10 mm - Route clk inside layer
> CMD-BUS CLK: 39 CKE0m CS0: 49, 65 CKE1m CS1: 60, 68 UDQM, LDQM: 38, 47 BS0, BS1: 26, 26 RAS, CAS: 46, 42 WE: 46
SDRAM PHY Rise / Fall / Setup / Hold times: - 1 ns - t_setup-time: 1.5 ns - t_hold-time: 1 ns MCU Rise / Fall / Setup / Hold times -
SDRAM DECOUPLING
SDRAM
> ADDR-bus: A0, A3: 46, 46, 47, 48 A4, A7: 38, 37, 40, 38.7 A8, A11: 36, 34, 44, 34 A12: 31
- Size: 4 M x 4 banks x 16-bits SDRAM (256 Mbits) - Voltage: 3V3

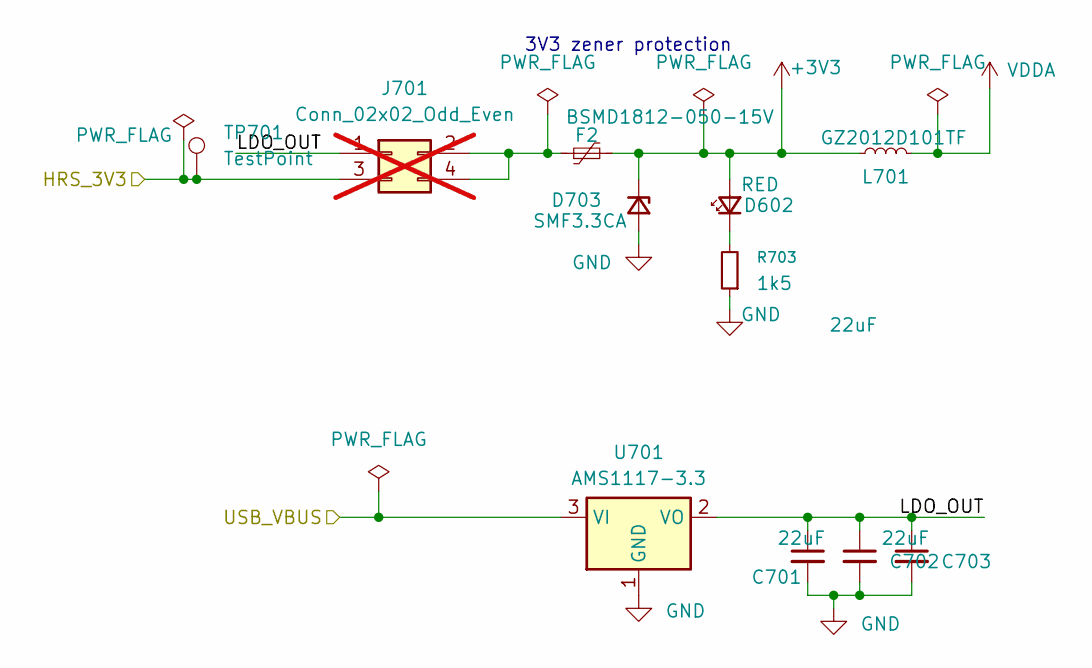
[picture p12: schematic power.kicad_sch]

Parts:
C701, C702, C703: 22uF; C_0603_1608Metric; MPN CL10A226MQ8NRNC
D602: RED; LED_0603_1608Metric; MPN KT-0603R
D703: SMF3.3CA; D_SOD-123F; MPN SMF3.3CA
F2: BSMD1812-050-15V; Fuse_1812_4532Metric; MPN BSMD1812-050-15V
J701: Conn_02x02_Odd_Even; PinHeader_2x02_P2.54mm_Vertical; not fitted
L701: GZ2012D101TF; L_0805_2012Metric; MPN GZ2012D101TF
R703: 1k5; R_0402_1005Metric; MPN 0402WGF1501TCE
TP701: TestPoint; PinSocket_1x01_P1.27mm_Vertical
U701: AMS1117-3.3; SOT-223-3_TabPin2; MPN AMS1117-3.3

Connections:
+3V3: D602.2 (A), D703.1 (K), F2.2, L701.1; also elsewhere on the board
/connectors/HRS_3V3: J701.3, TP701.1; also elsewhere on the board
/power/LDO_OUT: C701.1, C702.1, C703.1, J701.1, U701.2 (VO)
/power/USB_VBUS: U701.3 (VI); also elsewhere on the board
GND: C701.2, C702.2, C703.2, D703.2 (A), R703.1, U701.1 (GND); also elsewhere on the board
unnamed: D602.1 (K), R703.2
unnamed: F2.1, J701.2, J701.4
VDDA: L701.2; also elsewhere on the board

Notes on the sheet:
3V3 zener protection

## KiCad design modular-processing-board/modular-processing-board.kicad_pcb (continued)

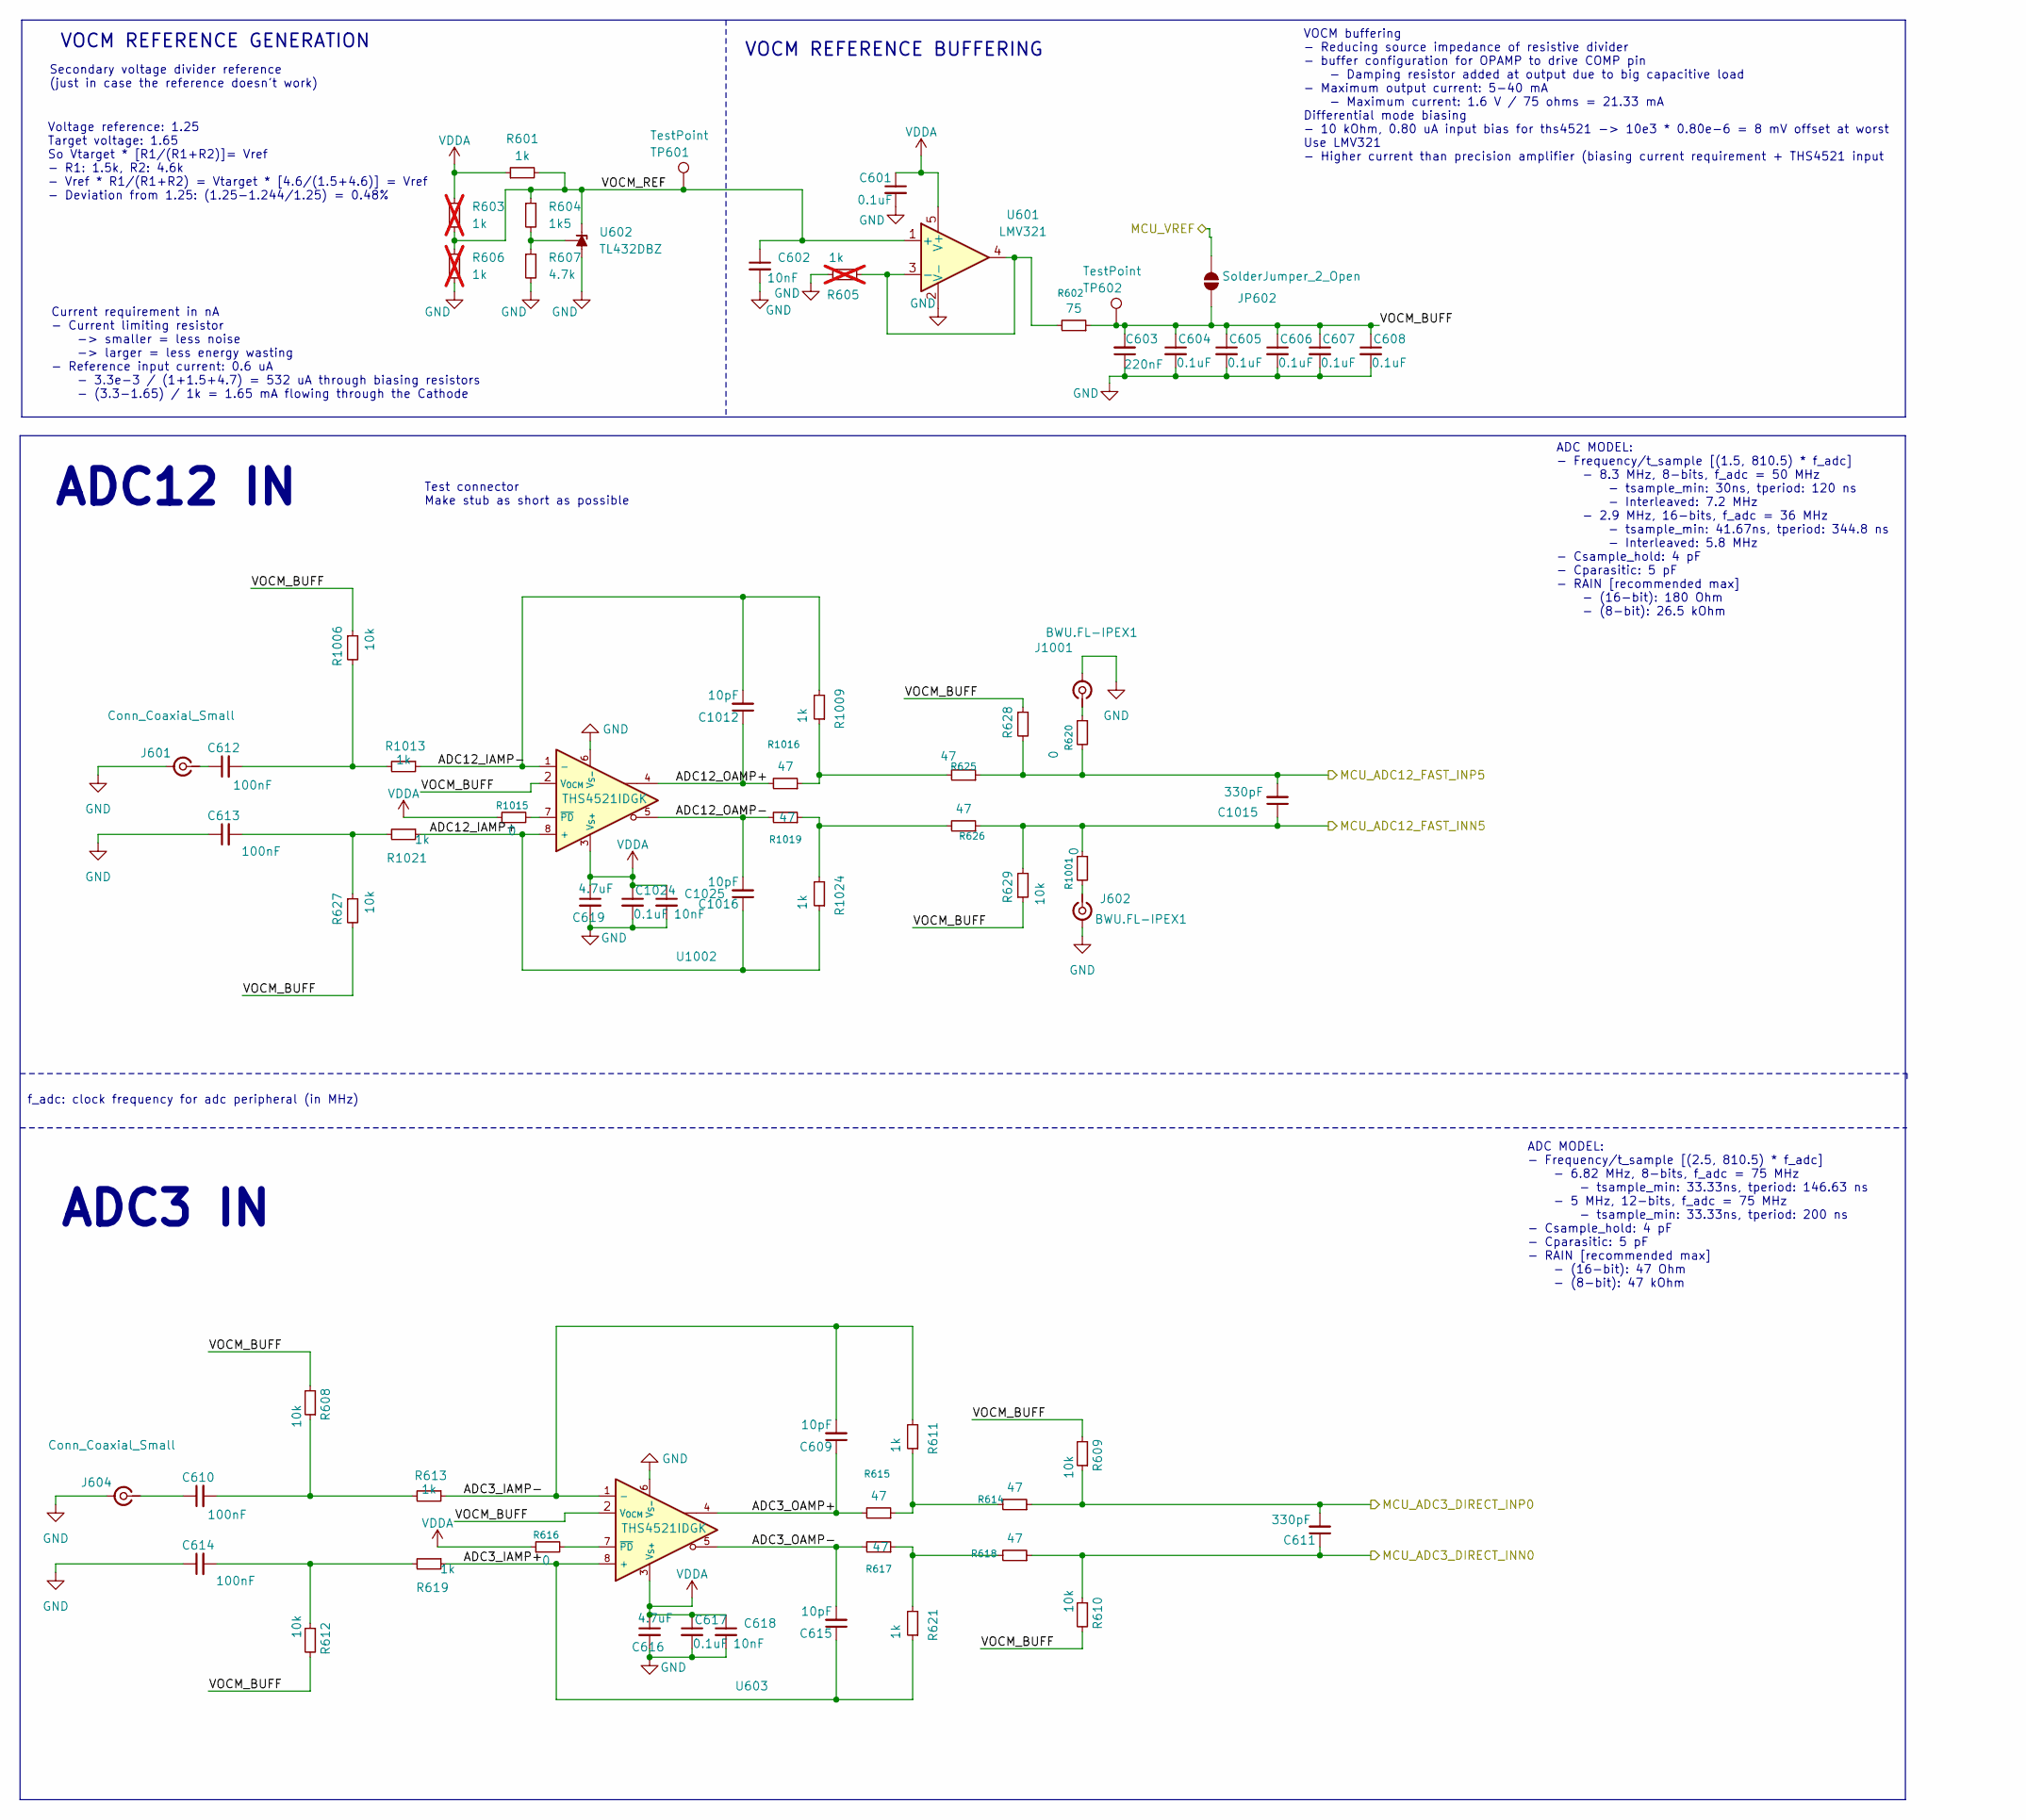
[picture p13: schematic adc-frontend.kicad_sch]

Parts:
C601, C604, C605, C606, C607, C608, C617, C1024: 0.1uF; C_0402_1005Metric; MPN CL05B104KB54PNC
C602, C618, C1025: 10nF; C_0402_1005Metric; MPN CL05B103KB5NNNC
C603: 220nF; C_0402_1005Metric; MPN CL05B224KO5NNNC
C609, C615, C1012, C1016: 10pF; C_0603_1608Metric_Pad1.08x0.95mm_HandSolder; MPN CL10C100JB8NNNC
C610, C612, C613, C614: 100nF; C_0603_1608Metric; MPN CC0603KRX7R9BB104
C611, C1015: 330pF; C_0603_1608Metric_Pad1.08x0.95mm_HandSolder; MPN CL10C331JB8NNNC
C616, C619: 4.7uF; C_0402_1005Metric; MPN CL05A475MP5NRNC
J601, J604: Conn_Coaxial_Small; SMA_Amphenol_901-144_Vertical; MPN BWSMA-KE-Z001
J602, J1001: BWU.FL-IPEX1; MPN BWU.FL-IPEX1
JP602: SolderJumper_2_Open; SolderJumper-2_P1.3mm_Open_Pad1.0x1.5mm
R601, R611, R613, R619, R621, R1009, R1013, R1021, R1024: 1k; R_0603_1608Metric; MPN 0603WAF1001T5E
R602: 75; R_0603_1608Metric; MPN 0603WAF750JT5E
R603, R605, R606: 1k; R_0603_1608Metric; MPN 0603WAF1001T5E; not fitted
R604: 1k5; R_0603_1608Metric; MPN 0603WAF1501T5E
R607: 4.7k; R_0603_1608Metric; MPN 0603WAF4701T5E
R608, R609, R610, R612, R627, R628, R629, R1006: 10k; R_0603_1608Metric; MPN 0603WAF1002T5E
R614, R615, R617, R618, R625, R626, R1016, R1019: 47; R_0603_1608Metric; MPN 0603WAF470JT5E
R616, R620, R1001, R1015: 0; R_0603_1608Metric; MPN 0603WAF0000T5E
TP601, TP602: TestPoint; PinSocket_1x01_P1.27mm_Vertical
U601: LMV321; SOT-23-5; MPN LMV321IDBVR
U602: TL432DBZ; SOT-23; MPN TL432
U603, U1002: THS4521IDGK; VSSOP-8_3x3mm_P0.65mm; MPN THS4521IDGKR

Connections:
/adc-frontend/ADC3_IAMP+: C615.1, R619.1, R621.1, U603.8 (+)
/adc-frontend/ADC3_IAMP-: C609.2, R611.2, R613.1, U603.1 (-)
/adc-frontend/ADC3_OAMP+: C609.1, R615.2, U603.4
/adc-frontend/ADC3_OAMP-: C615.2, R617.2, U603.5
/adc-frontend/ADC12_IAMP+: C1016.1, R1021.1, R1024.1, U1002.8 (+)
/adc-frontend/ADC12_IAMP-: C1012.2, R1009.2, R1013.1, U1002.1 (-)
/adc-frontend/ADC12_OAMP+: C1012.1, R1016.2, U1002.4
/adc-frontend/ADC12_OAMP-: C1016.2, R1019.2, U1002.5
/adc-frontend/MCU_ADC3_DIRECT_INN0: C611.1, R610.1, R618.1; also elsewhere on the board
/adc-frontend/MCU_ADC3_DIRECT_INP0: C611.2, R609.1, R614.1; also elsewhere on the board
/adc-frontend/MCU_ADC12_FAST_INN5: C1015.1, R626.1, R629.2, R1001.1; also elsewhere on the board
/adc-frontend/MCU_ADC12_FAST_INP5: C1015.2, R620.2, R625.1, R628.2; also elsewhere on the board
/adc-frontend/MCU_VREF: JP602.2 (B); also elsewhere on the board
/adc-frontend/VOCM_BUFF: C603.2, C604.1, C605.1, C606.1, C607.1, C608.1, JP602.1 (A), R602.1, R608.2, R609.2, R610.2, R612.2, R627.2, R628.1, R629.1, R1006.1, TP602.1, U603.2 (V_{OCM}), U1002.2 (V_{OCM})
/adc-frontend/VOCM_REF: C602.1, R601.2, R603.2, R604.1, R606.1, TP601.1, U601.1 (+), U602.2 (K)
GND: C601.2, C602.2, C603.1, C604.2, C605.2, C606.2, C607.2, C608.2, C613.1, C614.1, C616.2, C617.2, C618.2, C619.2, C1024.2, C1025.2, J601.2 (Ext), J602.2 (Ext), J604.2 (Ext), J1001.2 (Ext), R605.1, R606.2, R607.2, U601.2 (V-), U602.3 (A), U603.6 (V_{S-}), U1002.6 (V_{S-}); also elsewhere on the board
unnamed: C610.2, R608.1, R613.2
unnamed: C612.2, R1006.2, R1013.2
unnamed: C613.2, R627.1, R1021.2
unnamed: C614.2, R612.1, R619.2
unnamed: C612.1, J601.1 (In)
unnamed: J602.1 (In), R1001.2
unnamed: C610.1, J604.1 (In)
unnamed: J1001.1 (In), R620.1
unnamed: R611.1, R614.2, R615.1
unnamed: R617.1, R618.2, R621.2
unnamed: R625.2, R1009.1, R1016.1
unnamed: R626.2, R1019.1, R1024.2
unnamed: R602.2, R605.2, U601.3 (-), U601.4
unnamed: R604.2, R607.1, U602.1 (REF)
unnamed: R616.2, U603.7 (~PD)
unnamed: R1015.2, U1002.7 (~PD)
VDDA: C601.1, C616.1, C617.1, C618.1, C619.1, C1024.1, C1025.1, R601.1, R603.1, R616.1, R1015.1, U601.5 (V+), U603.3 (V_{S+}), U1002.3 (V_{S+}); also elsewhere on the board

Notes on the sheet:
ADC MODEL: - Frequency/t_sample [(1.5, 810.5) * f_adc] - 8.3 MHz, 8-bits, f_adc = 50 MHz - tsample_min: 30ns, tperiod: 120 ns - Interleaved: 7.2 MHz - 2.9 MHz, 16-bits, f_adc = 36 MHz - tsample_min: 41.67ns, tperiod: 344.8 ns - Interleaved: 5.8 MHz - Csample_hold: 4 pF - Cparasitic: 5 pF - RAIN [re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
VOCM REFERENCE GENERATION
ADC12 IN
Voltage reference: 1.25 Target voltage: 1.65 So Vtarget * [R1/(R1+R2)]= Vref - R1: 1.5k, R2: 4.6k - Vref * R1/(R1+R2) = Vtarget * [4.6/(1.5+4.6)] = Vref - Deviation from 1.25: (1.25-1.244/1.25) = 0.48%
VOCM REFERENCE BUFFERING
Secondary voltage divider reference (just in case the reference doesn't work)
Test connector Make stub as short as possible
ADC MODEL: - Frequency/t_sample [(2.5, 810.5) * f_adc] - 6.82 MHz, 8-bits, f_adc = 75 MHz - tsample_min: 33.33ns, tperiod: 146.63 ns - 5 MHz, 12-bits, f_adc = 75 MHz - tsample_min: 33.33ns, tperiod: 200 ns - Csample_hold: 4 pF - Cparasitic: 5 pF - RAIN [recommended max] - (16-bit): 47 Ohm - (8-bit)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
VOCM buffering - Reducing source impedance of resistive divider - buffer configuration for OPAMP to drive COMP pin - Damping resistor added at output due to big capacitive load - Maximum output current: 5-40 mA - Maximum current: 1.6 V / 75 ohms = 21.33 mA Differential mode biasing - 10 kOhm, 0.80 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
Current requirement in nA - Current limiting resistor -> smaller = less noise -> larger = less energy wasting - Reference input current: 0.6 uA - 3.3e-3 / (1+1.5+4.7) = 532 uA through biasing resistors - (3.3-1.65) / 1k = 1.65 mA flowing through the Cathode
f_adc: clock frequency for adc peripheral (in MHz)
ADC3 IN

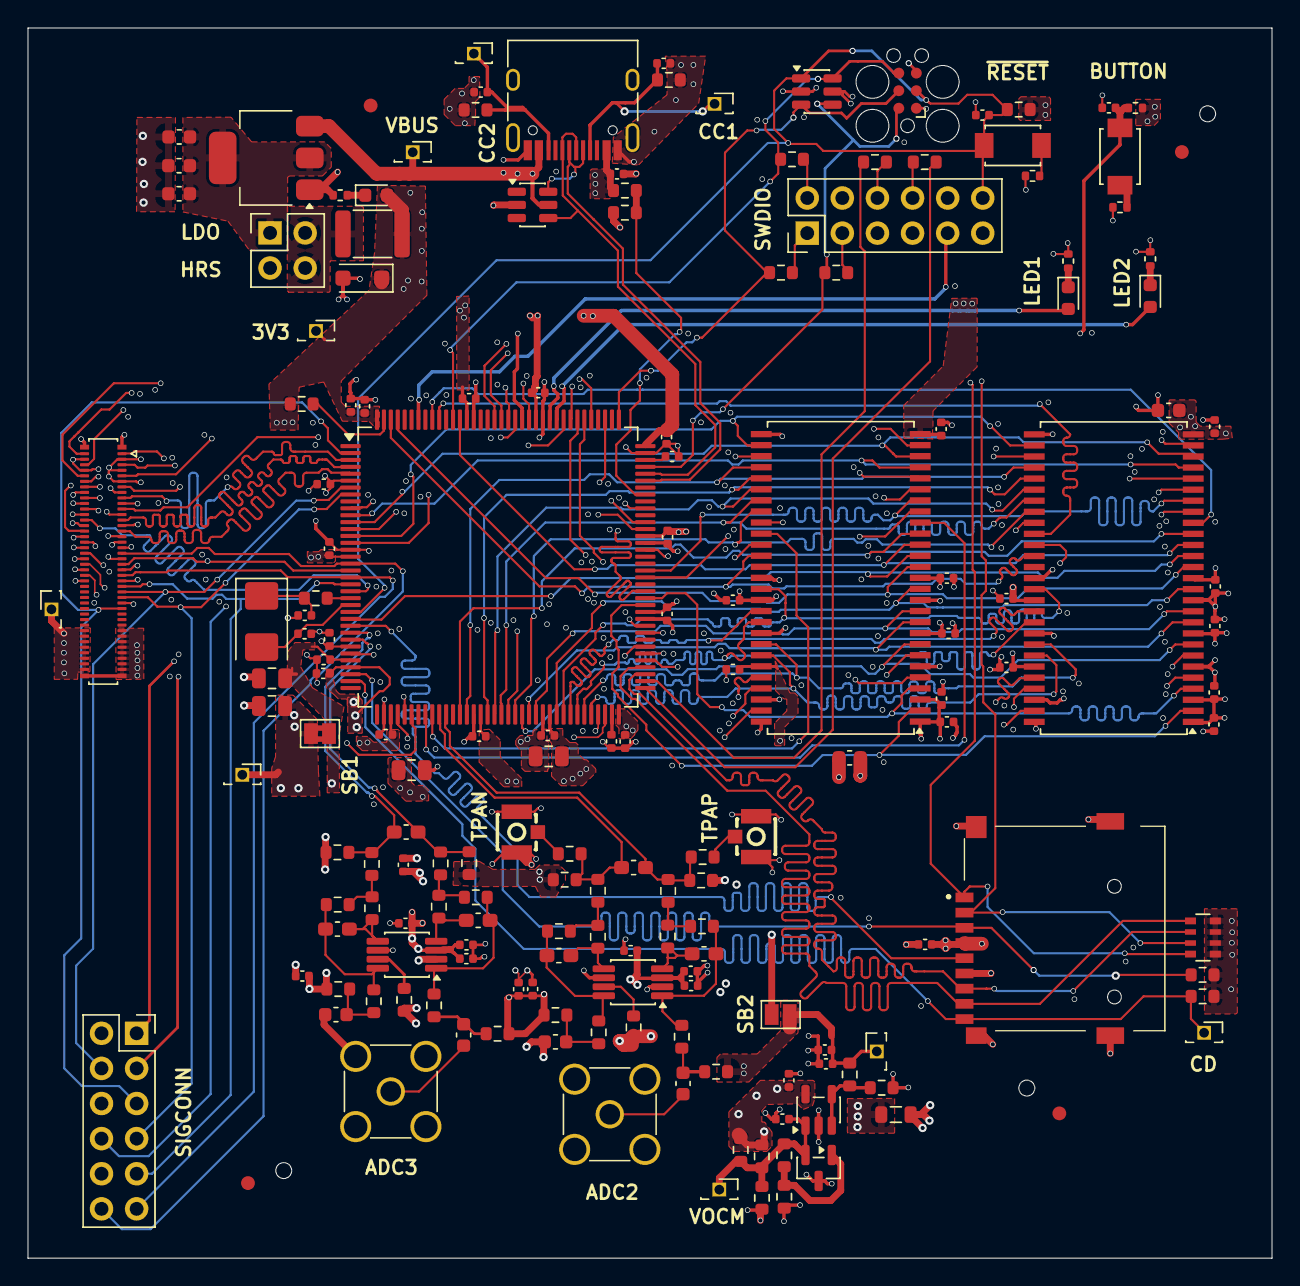
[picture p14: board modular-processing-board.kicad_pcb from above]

Board: 6 copper layers, 90.0 x 89.0 mm, 177 parts (0 on the bottom side), 145 nets.

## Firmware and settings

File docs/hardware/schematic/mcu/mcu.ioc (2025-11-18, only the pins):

Mcu.UserName=STM32H723ZGTx
PA0.Signal=SDMMC2_CMD
PA1.GPIO_Label=IO_SDMMC_CD
PA1.Signal=GPIO_Input
PA11.Signal=USB_OTG_HS_DM
PA12.Signal=USB_OTG_HS_DP
PA13(JTMS/SWDIO).Signal=DEBUG_JTMS-SWDIO
PA14(JTCK/SWCLK).Signal=DEBUG_JTCK-SWCLK
PA4.Signal=PSSI_DE
PA5.Signal=PSSI_D14
PA6.Signal=PSSI_PDCK
PA9.GPIO_Label=USB_SENSE
PA9.Signal=GPIO_Input
PB0.Signal=ADCx_INN5
PB1.Signal=ADCx_INP5
PB10.Signal=I2C2_SCL
PB11.Signal=I2C2_SDA
PB12.Signal=UART5_RX
PB13.Signal=UART5_TX
PB14.Signal=SDMMC2_D0
PB15.Signal=SDMMC2_D1
PB3(JTDO/TRACESWO).Signal=DEBUG_JTDO-SWO
PB5.Signal=FMC_SDCKE1
PB6.Signal=FMC_SDNE1
PC0.Signal=FMC_SDNWE
PC1.Signal=SDMMC2_CK
PC10.Signal=PSSI_D8
PC12.Signal=PSSI_D9
PC13.GPIO_Label=PBOOST_EN
PC13.Signal=GPIO_Output
PC14-OSC32_IN.GPIO_Label=PSEPIC_EN
PC14-OSC32_IN.Signal=GPIO_Output
PC2_C.Signal=ADC3_INN1
PC3_C.Signal=ADC3_INP1
PC4.Signal=FMC_SDNE0
PC5.Signal=FMC_SDCKE0
PC6.Signal=PSSI_D0
PC7.Signal=PSSI_D1
PC9.Signal=PSSI_D3
PD0.Signal=FMC_D2_DA2
PD1.Signal=FMC_D3_DA3
PD10.Signal=FMC_D15_DA15
PD12.Signal=PSSI_D12
PD13.Signal=PSSI_D13
PD14.Signal=FMC_D0_DA0
PD15.Signal=FMC_D1_DA1
PD2.Signal=PSSI_D11
PD3.Signal=PSSI_D5
PD4.GPIO_Label=LED2
PD4.Signal=GPIO_Output
PD5.GPIO_Label=LED1
PD5.Signal=GPIO_Output
PD6.Signal=PSSI_D10
PD7.GPIO_Label=BUTTON_1
PD7.Signal=GPIO_Input
PD8.Signal=FMC_D13_DA13
PD9.Signal=FMC_D14_DA14
PE0.Signal=FMC_NBL0
PE1.Signal=FMC_NBL1
PE10.Signal=FMC_D7_DA7
PE11.Signal=FMC_D8_DA8
PE12.Signal=FMC_D9_DA9
PE13.Signal=FMC_D10_DA10
PE14.Signal=FMC_D11_DA11
PE15.Signal=FMC_D12_DA12
PE3.GPIO_Label=ADC_ALERT
PE3.Signal=GPIO_Input
PE4.Signal=PSSI_D4
PE5.Signal=PSSI_D6
PE6.Signal=PSSI_D7
PE7.Signal=FMC_D4_DA4
PE8.Signal=FMC_D5_DA5
PE9.Signal=FMC_D6_DA6
PF0.Signal=FMC_A0
PF1.Signal=FMC_A1
PF10.Signal=PSSI_D15
PF11.Signal=FMC_SDNRAS
PF12.Signal=FMC_A6
PF13.Signal=FMC_A7
PF14.Signal=FMC_A8
PF15.Signal=FMC_A9
PF2.Signal=FMC_A2
PF3.Signal=FMC_A3
PF4.Signal=FMC_A4
PF5.Signal=FMC_A5
PF6.Signal=TIM23_CH1
PF7.Signal=S_TIM23_CH2
PF8.Signal=S_TIM23_CH3
PF9.Signal=S_TIM23_CH4
PG0.Signal=FMC_A10
PG1.Signal=FMC_A11
PG10.Signal=PSSI_D2
PG11.Signal=SDMMC2_D2
PG12.Signal=SDMMC2_D3
PG15.Signal=FMC_SDNCAS
PG2.Signal=FMC_A12
PG4.Signal=FMC_A14_BA0
PG5.Signal=FMC_A15_BA1
PG8.Signal=FMC_SDCLK
PG9.Signal=PSSI_RDY
PH0-OSC_IN.Signal=RCC_OSC_IN
PH1-OSC_OUT.Signal=RCC_OSC_OUT

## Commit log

2025-10-07 minor comments (next) pick RAM, add connectors
    [mcu.kicad_sch]
2025-10-11 research on best communication interfaces, added sdram
    [mcu.kicad_sch, modular-processing-board.kicad_sch, sdram.kicad_sch]
2025-10-12 basicsic pinout/component selection done, added SDRAM pins (next) Add parallel pins, add connections to pinheaders
    [mcu.kicad_sch, modular-processing-board.kicad_sch, sdram.kicad_sch]
2025-10-12 added parallel slave bus, SWO, USB (next) add small PSU for CPU-board, add ethernet PHY, add correct USB connector
    [mcu.kicad_sch, modular-processing-board.kicad_sch, sdram.kicad_sch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]
2025-10-14 added ESD protection, USB connector, SD-CARD, decoupling caps (next) add appropriate VREF, COAX for ADC, board2board connectors and connect wiring
    [connectors.kicad_sch, mcu.kicad_sch, modular-processing-board.kicad_sch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]
2025-10-14 added new, better suited possible connectors
    [mcu.kicad_sch]
2025-10-18 decided on fully differential configuratinon with ths4521 for both ADC inputs
    [connectors.kicad_sch, mcu.kicad_sch]
2025-10-19 Finished basic HW (next) Fix-up all labeling, then start laying out
    [adc-frontend.kicad_sch, connectors.kicad_sch, mcu.kicad_sch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]
2025-10-23 completed schematic
    [adc-frontend.kicad_sch, connectors.kicad_sch, mcu.kicad_sch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]
2025-10-25 various changes to schematic (next) add bias resistors after testing results on acoustic-carrier-board
    [adc-frontend.kicad_sch, mcu.kicad_sch, modular-processing-board.kicad_pcb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]
2025-10-28 started layout
    [adc-frontend.kicad_sch, mcu.kicad_sch, modular-processing-board.kicad_pcb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]
2025-10-30 removed power input jumpers to single one, added trace impedances and production restrictions (next) route sdram
    [adc-frontend.kicad_sch, mcu.kicad_sch, modular-processing-board.kicad_pcb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]
2025-11-04 figuring out delay matching for sdram
    [power.kicad_sch, sdram.kicad_sch]
2025-11-06 checked timing for sdram, routing
    [modular-processing-board.kicad_pcb, sdram.kicad_sch]
2025-11-07 rough length mamatching for sdram (next) route PSSI-bus
    [connectors.kicad_sch, mcu.kicad_sch, modular-processing-board.kicad_pcb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]
2025-11-09 replaced sdmmc connector, added smmc trace, added u.fl. connectors
    [adc-frontend.kicad_sch, mcu.kicad_sch, modular-processing-board.kicad_pcb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]
2025-11-09 redid frontend layout, routed diff adc wires (next) finish routing, start with decoupling and planes
    [modular-processing-board.kicad_pcb]
2025-11-09 reconnected vref
    [adc-frontend.kicad_sch, connectors.kicad_sch, mcu.kicad_sch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]
2025-11-10 routing hardware (next) reroute the CLK and A12
    [modular-processing-board.kicad_pcb]
2025-11-13 added GND conconnections (next) remove 8th layer
    [modular-processing-board.kicad_pcb]
2025-11-15 layed out most components (next) cadd vias for impedance reduction for high-speed signals, check impedance of signals
    [adc-frontend.kicad_sch, mcu.kicad_sch, modular-processing-board.kicad_pcb]
2025-11-16 changeed layer 3 traces to 50 ohm-impedance tracks
    [modular-processing-board.kicad_pcb]
2025-11-16 added return vias, solved routing errors (next) check impedance of top-bottom layer signals, schematic check
    [modular-processing-board.kicad_pcb]
2025-11-16 completed schematic + layout (next) do footprint checks etc.
    [mcu.kicad_sch, modular-processing-board.kicad_pcb, usb_eth.kicad_sch]
2025-11-18 checking SDMMC SD-card interface (next) finish checking sd-card holder, check connectors, frontend and power
    [mcu.kicad_sch, modular-processing-board.kicad_pcb, usb_eth.kicad_sch]
2025-11-19 finished schematic checks, added extra capacitors on LDO output (next) add holes to board / board shape, do layout checks
    [connectors.kicad_sch, modular-processing-board.kicad_pcb, power.kicad_sch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]
2025-11-20 checked components part numbers (next) board checks
    [adc-frontend.kicad_sch, mcu.kicad_sch, modular-processing-board.kicad_pcb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]
2025-11-20 matched PSSI bus lenghts
    [adc-frontend.kicad_sch, connectors.kicad_sch, mcu.kicad_sch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]
2025-11-22 finished sdram length matching (next) check trace closeness for ADC-signals, check impedances, check SDMMC lengths
    [modular-processing-board.kicad_pcb]
2025-11-22 checked differential impedances + SDMMC lenghts (next) check impedances of SE-signals
    [mcu.kicad_sch, modular-processing-board.kicad_pcb]
2025-11-23 finish modular-processing-hw board checks, prepare gerbers for manufacturing and perform checks
    [adc-frontend.kicad_sch, mcu.kicad_sch, modular-processing-board.kicad_pcb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]
2025-11-23 minor changes in BOM and DNP-components
    [adc-frontend.kicad_sch, connectors.kicad_sch, mcu.kicad_sch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]
2025-11-26 changed footprints (next) try uploading to jlcpcb for manufacturing, change crystal if required for economic assembly
    [adc-frontend.kicad_sch, mcu.kicad_sch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]
2025-11-28 processing hw submitted
    [mcu.kicad_sch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]
2025-11-28 sending in for manufacturing
    [modular-processing-board.kicad_pcb]
2025-11-30 second version sent in
    [modular-processing-board-B_Cu.gbl, modular-processing-board-B_Mask.gbs, modular-processing-board-B_Paste.gbp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]
2025-12-02 [hw] Merged zones, redrew traces for minimal impedance modification (next) recheck all SDRAM traces + PSSI traces
    [modular-processing-board.kicad_pcb]
2025-12-02 finalized layout for 3rd submission attempt to jlc
    [modular-processing-board.kicad_pcb]
2025-12-03 changed testpoints
    [adc-frontend.kicad_sch, mcu.kicad_sch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]
2025-12-03 changed header of pos-file
    [modular-processing-board-top-pos.csv]
2026-05-17 minor change in fw
    [sdram.kicad_sch]

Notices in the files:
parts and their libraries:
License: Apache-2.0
